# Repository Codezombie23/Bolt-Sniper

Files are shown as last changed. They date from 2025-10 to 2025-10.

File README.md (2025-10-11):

# 'Ignis' Bolt Action Sniper Blaster

## Description

Ignis is a Bolt Action Sniper rifle inspired by the Warhammer 40k Guards Sniper rifle. It uses a double stacked mag, designed by Misplaced Moose, to hold 20 rounds in a mag no longer than a normal 10 round Talon style mag.

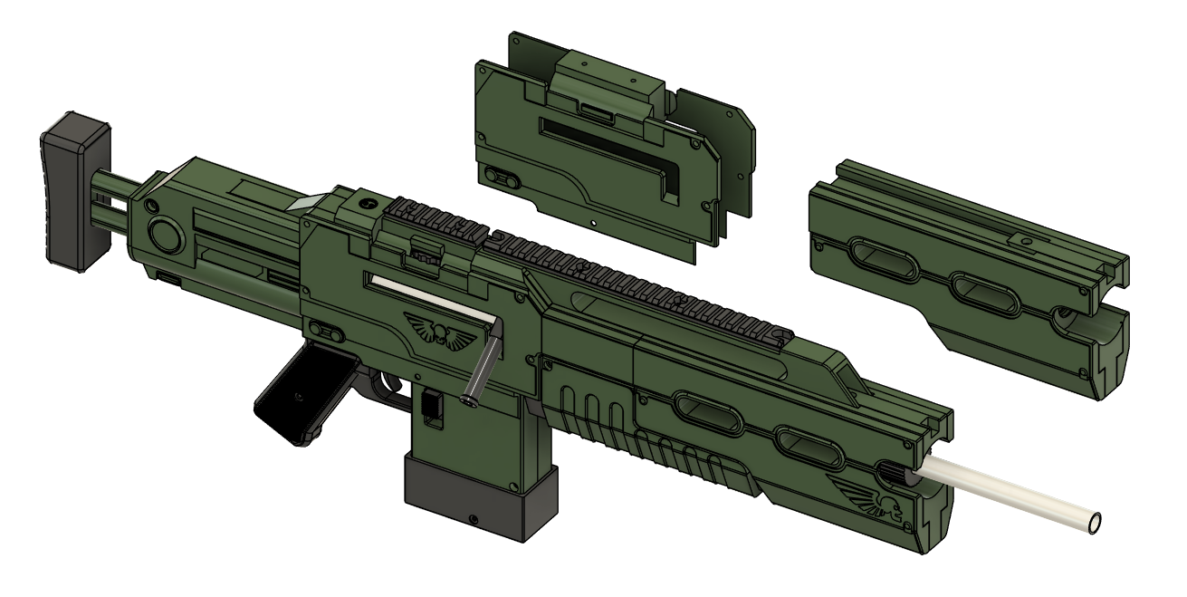
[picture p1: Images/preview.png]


### Features
- 110 > 130 adjustable FPS (WIP)
- 20 round capacity
- 450mm long barrel
- Uses Misplaced Moose's Moose Deuce double stacked mags.
- Optional adjustable optics rail

# Assembly Instructions
Start Here\
**[Assembly guide (incomplete)](Instructions/Instructions.md)**

## BOM (WIP)
- 1x - D12580 Spring - Springmasters \
	https://www.springmasters.com/shop/d12580/ 
- 4x - D11310 Spring - Springmasters \
	https://www.springmasters.com/shop/d11310/  
- 1x - 450mm Worker barrel - UK Nerfwar \
	https://www.uknerfwar.com/product-page/450mm-barrel
- 1x - 130mm Aluminium tube 38.1mm OD, 34.9mm ID - Use a supplier with a custom cutting service e.g: \
    https://www.metals4u.co.uk/materials/aluminium/aluminium-tube/986-p \
    https://www.aluminium-online.co.uk/product/1-1-4-x-16swg-aluminium-round-tube/
	
- 3x - O-Ring - 2.62mm Section 29.82mm Bore NITRILE 70 Shore Rubber O-Rings - Simply bearings
- 2x - O-Ring - 1.5mm Section 10mm Bore NITRILE 70 Shore Rubber O-Rings
- M4 Screws (todo)
- M3 Screws (todo)
- 2x - M4 grub screw (M4 x 8mm)

## Print settings
Most parts are printed at 10% gyroid or cross hatch, with three walls\
Otherwise parts are printed at four walls and 20% infill.

See instructions for more information.

# Licence
Creative Commons, Attribution-NonCommercial-ShareAlike 4.0 International \
CC BY-NC-SA 4.0 \
https://creativecommons.org/licenses/by-nc-sa/4.0/deed.en

# Attribution
- Moose Deuce Double Stack Magazines - Misplaced Moose \
	https://www.printables.com/model/1402880-double-stack-half-dart-nerf-magazines-aka-moose-du
- Cynthia - Barrel Nut and Piston front - Sillybuts \
	https://github.com/Sillybutts/Cynthia?tab=readme-ov-file

# These files are provided free of charge
However if you like these files then please consider supporting me. \
Supporting me helps pay for materials I use while prototyping. Thank you. \
You can donate via my BuyMeACoffee (Link Not available as not fully released)

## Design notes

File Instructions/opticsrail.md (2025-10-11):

# Assembling the Optics Rail
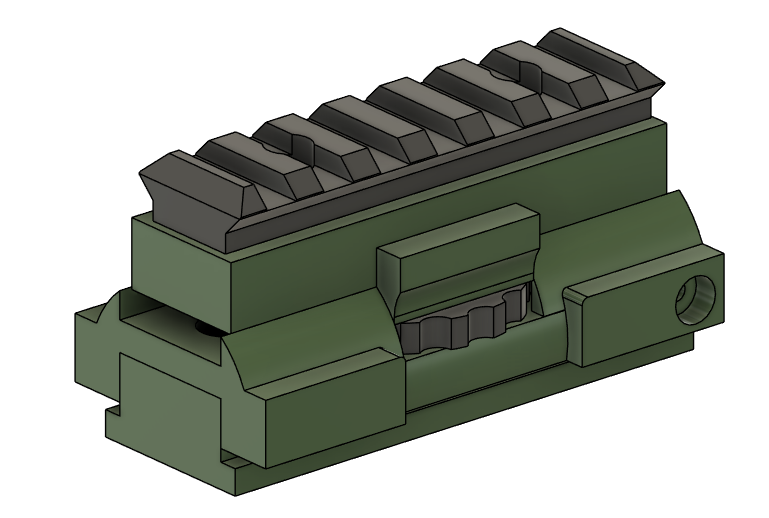
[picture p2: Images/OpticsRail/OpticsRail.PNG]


This is an optional step. When using optics there is not enough vertical control on some Optics to compensate for the short range and drop of darts. This rail allows for more vertical adjustment. If you don't plan on using Optics then you can print the solid part.

## Recommended Print Orientations

## Option 1 - Solid Optics Rail
### 3 Walls , 10% infill, No Supports needed
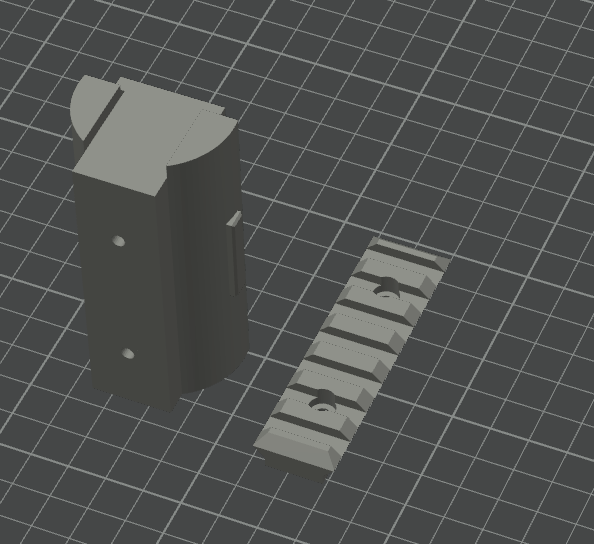
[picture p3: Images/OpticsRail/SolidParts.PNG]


## Option 2 - Adjustable Optics Rail
### 3 Walls , 10% infill, Tree Supports needed
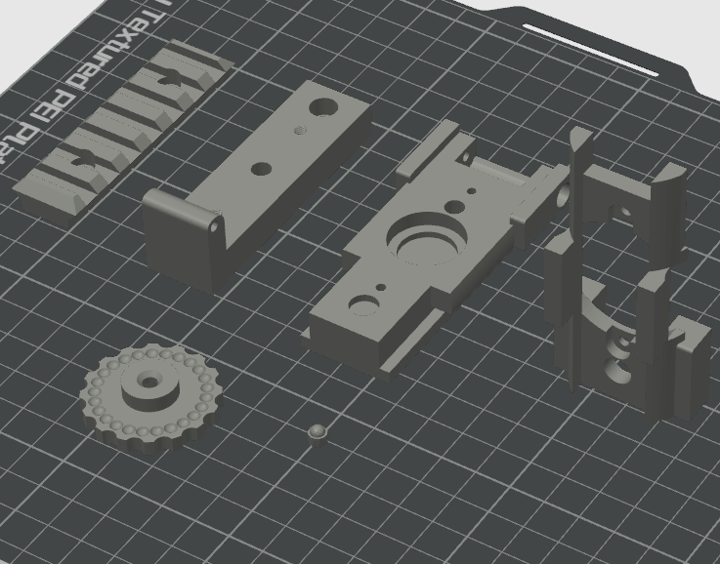
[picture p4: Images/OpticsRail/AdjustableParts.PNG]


## Tools
- 3.0mm Hex driver / Key
- 2.5mm Hex driver / Key

## Hardware

Common
- 2x M4x10 Socket Head Bolt

Option 2
- 1x 6702ZZ Bearing
- 1x 5mm x 12mm spring
- 1x 7mm x 20mm spring
- 4x M3 x 12mm Socket Head Bolt
- 1x M4 x 16mm Countersunk Screw
- 1x M4 Locknut
- 1x M4 Heatset Insert
- 2x M4 x 12mm Socket Head Bolt

## Assembly

If you are building the solid version of the optics mount, then skip to the last step.

Set a M4 heatset insert into the Optics Mount Top 
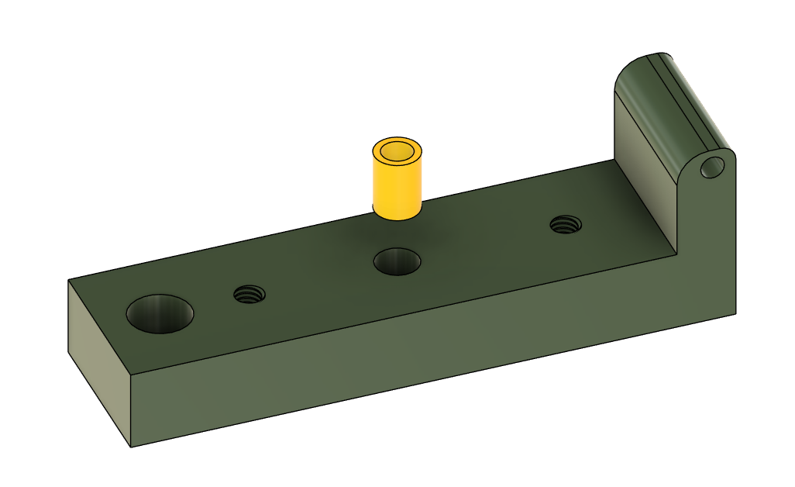
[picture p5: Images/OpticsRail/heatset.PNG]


Build the Thumb Wheel
Push the M4 Locknut into the hexagonal hole in the thumbwheel.
From the other side screw the M4 countersunk screw through the thumbwheel.
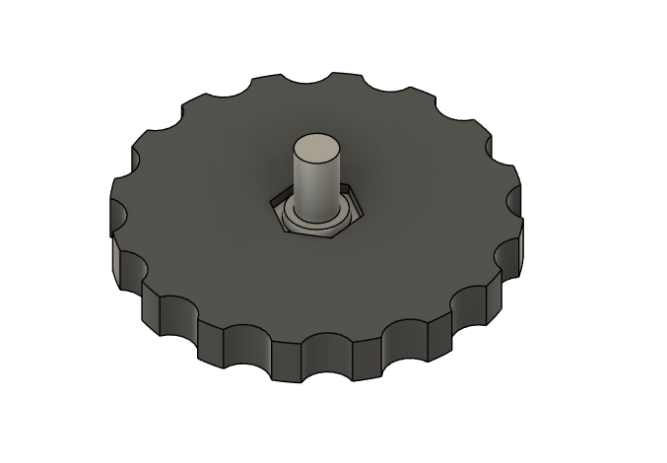
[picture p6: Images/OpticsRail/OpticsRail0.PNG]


Take the Optics Mount Lower, and press the 6702ZZ bearing into place.\
Insert the 5x12mm spring into the smaller hole, and place the locator carefully on top of the spring.
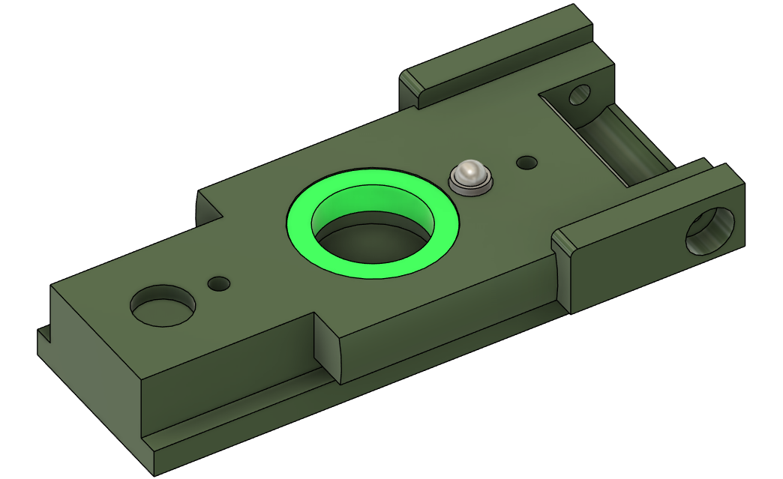
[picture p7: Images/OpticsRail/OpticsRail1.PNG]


Carefully lower the thumbwheel into the bearing in the Optics Mount Lower, taking care to not dislodge the locator.
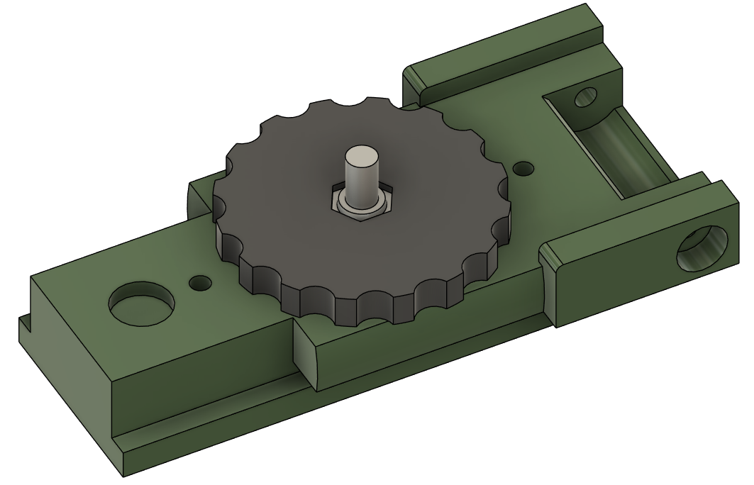
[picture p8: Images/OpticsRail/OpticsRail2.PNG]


Fit the Optics Mount Upper over the assembled parts. Again take care to ensure the wheel stays in place and the locator is not dislodged.
Use to M3x12 bolts to secure the Optics Mount Upper.
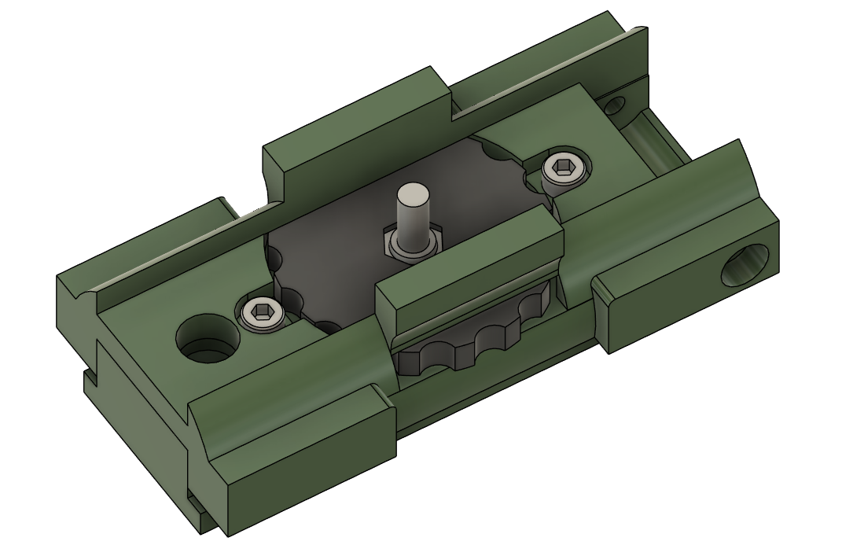
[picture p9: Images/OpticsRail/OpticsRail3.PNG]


Place the 7 x 20 Spring in the larger hole, then take the Optics Mount Top and use the thumb wheel to screw into the heatset insert in the Mount Top. 
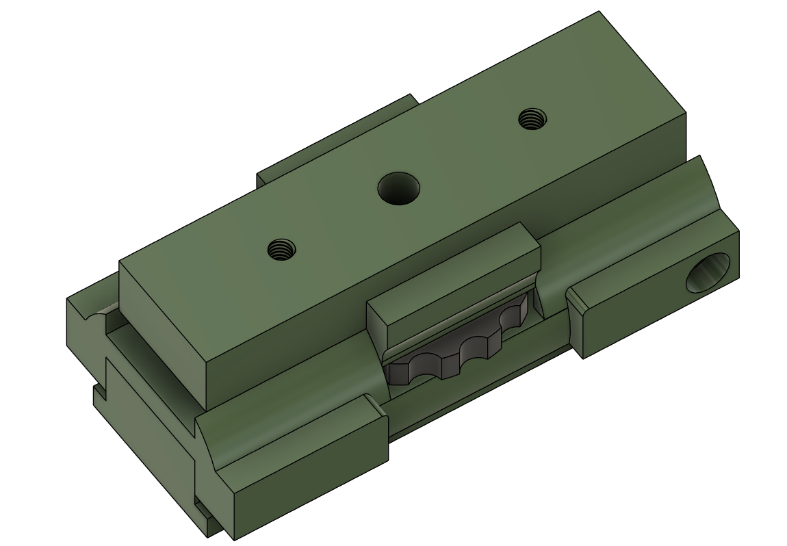
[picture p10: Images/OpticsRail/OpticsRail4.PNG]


Turn the thumb Wheel untill the side holes at the rear line up.
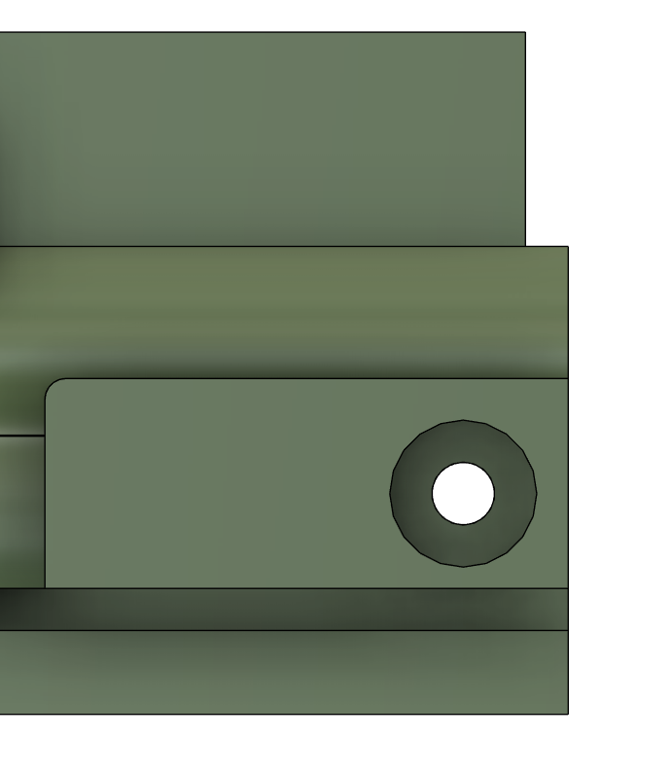
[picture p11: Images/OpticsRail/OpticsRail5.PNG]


Once the holes are lined up, screw in an M3x12mm bolt either side, once the screw is tight, back off half a turn to ensure movement.

Screw the Optics Rail into the Optics Mount Top with two M4x12 bolts. 
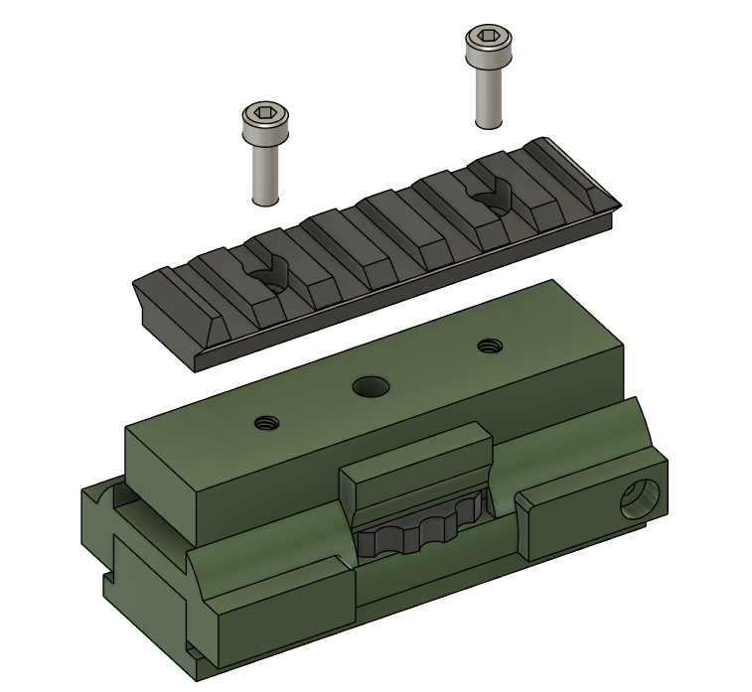
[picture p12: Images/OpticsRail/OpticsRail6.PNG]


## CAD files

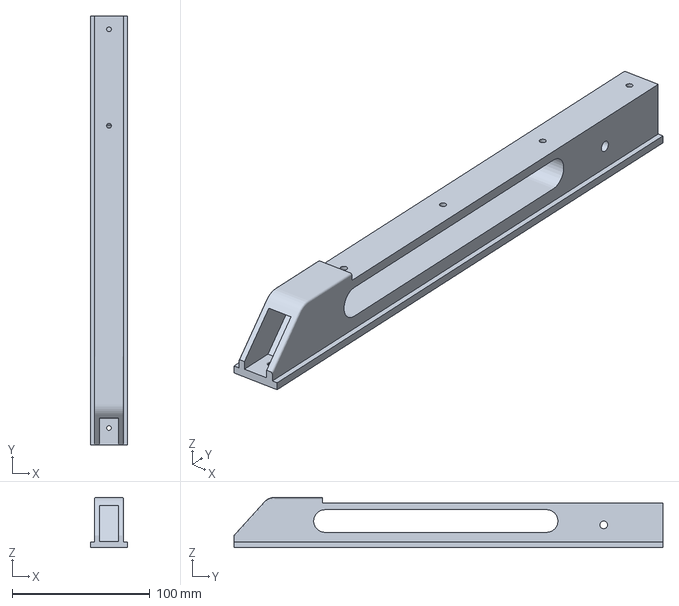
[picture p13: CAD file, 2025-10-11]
Print Files/Barrel Shroud/Upper Rail.3mf
27.2 x 311.6 x 36.5 mm

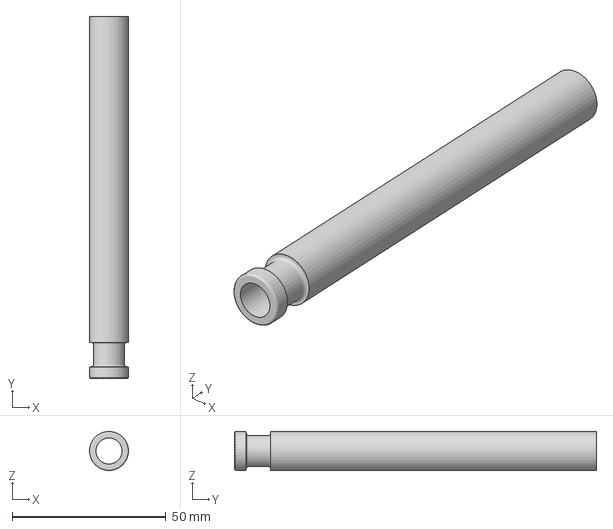
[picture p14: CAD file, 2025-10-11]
Print Files/Internals/Talon Style Ramrod Blunt.3mf
12.7 x 117.7 x 12.7 mm

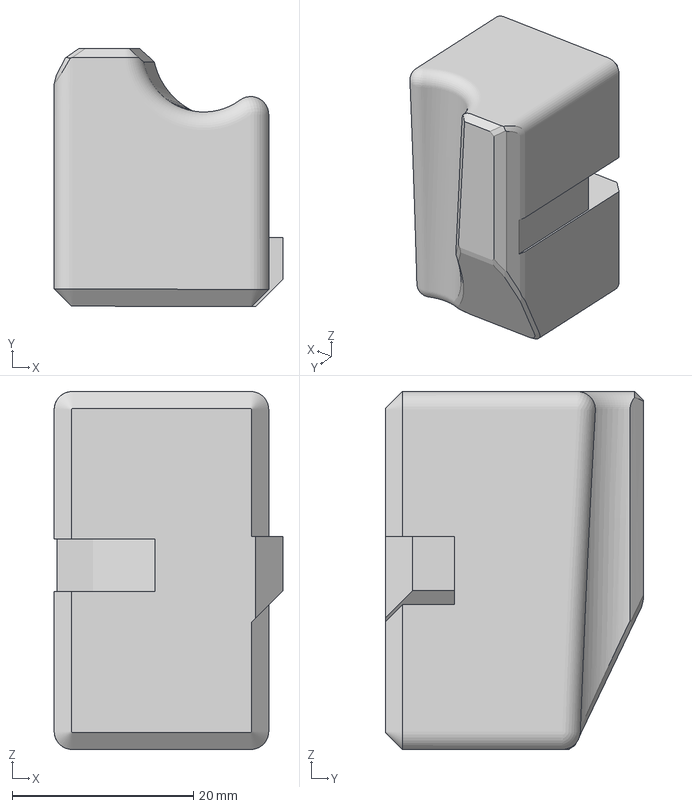
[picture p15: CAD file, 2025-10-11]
Print Files/Magazine/Follower.3mf
25.2 x 28.5 x 39.5 mm

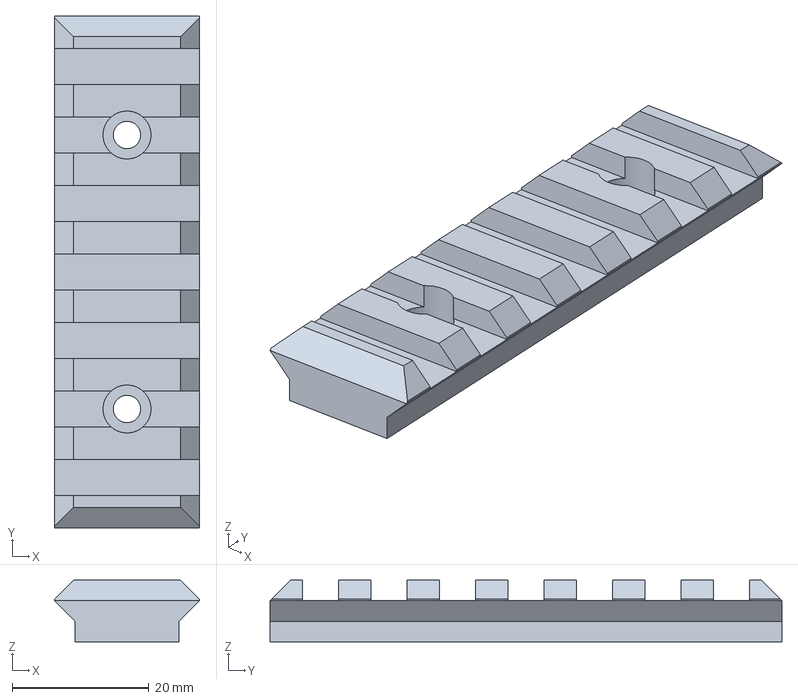
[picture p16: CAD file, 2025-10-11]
Print Files/OpticsRail/Optics Rail.3mf
21.2 x 74.8 x 9.00 mm

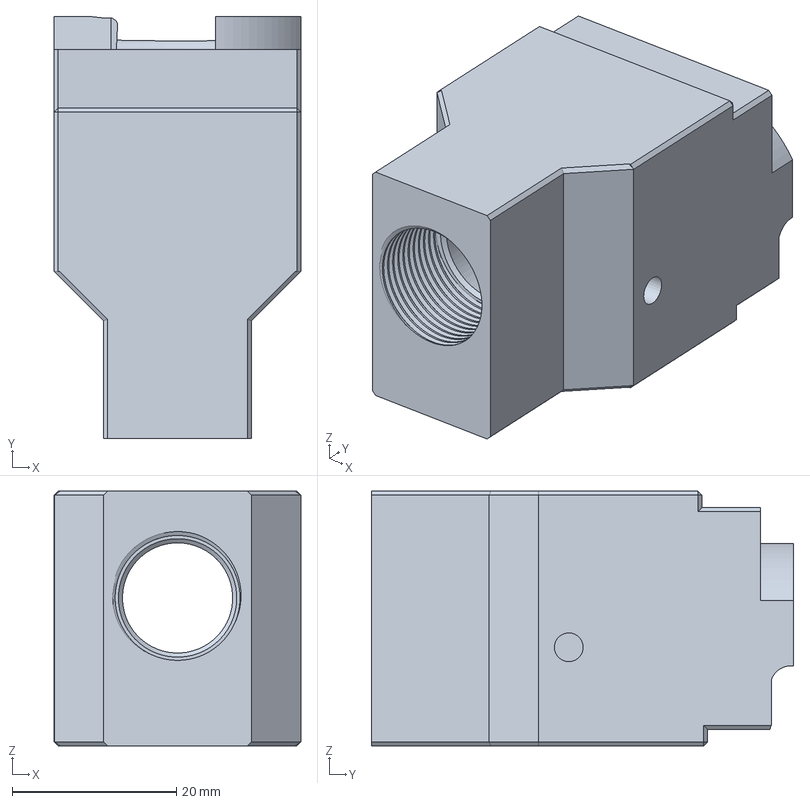
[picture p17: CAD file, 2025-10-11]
Print Files/Receiver/Feed Ramp Insert Worker Threaded.3mf
30.0 x 51.3 x 31.0 mm

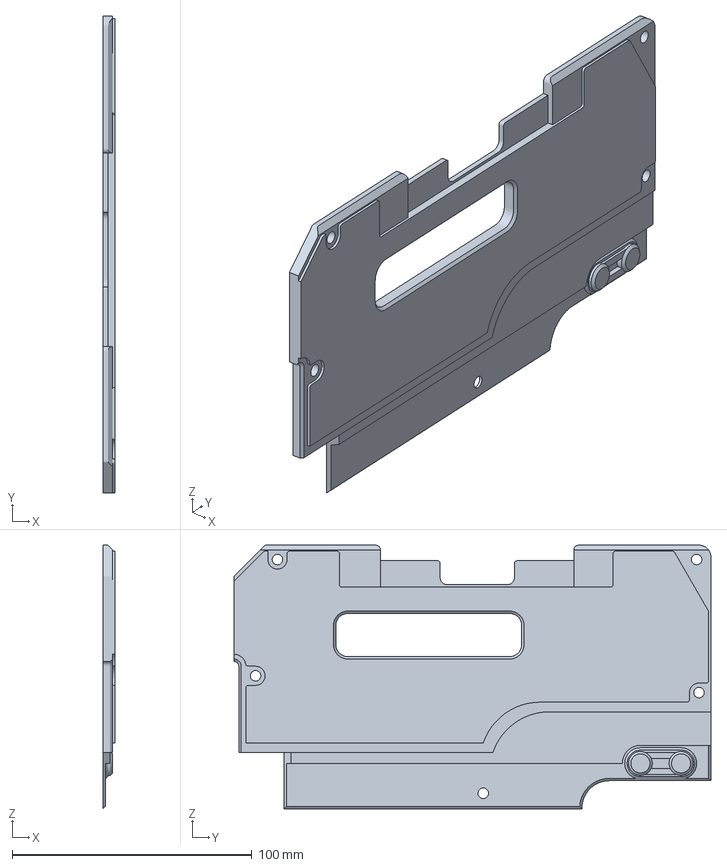
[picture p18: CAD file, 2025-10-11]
Print Files/Shell/SidePanel RHS Clean.3mf
5.00 x 199.0 x 110.0 mm

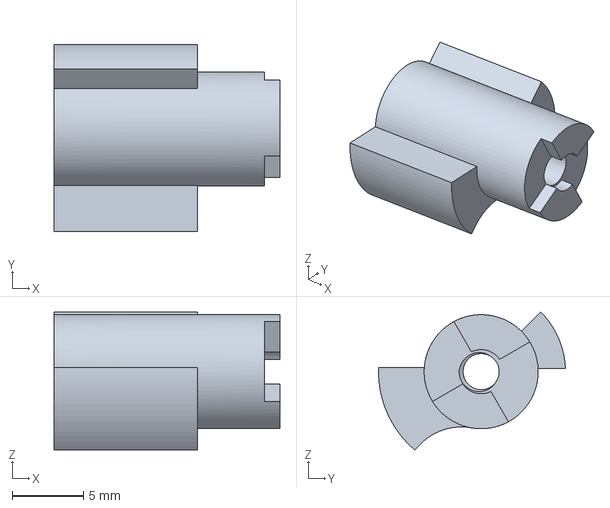
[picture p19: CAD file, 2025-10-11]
Print Files/Trigger Group/Safety Cam.3mf
15.9 x 13.1 x 9.67 mm

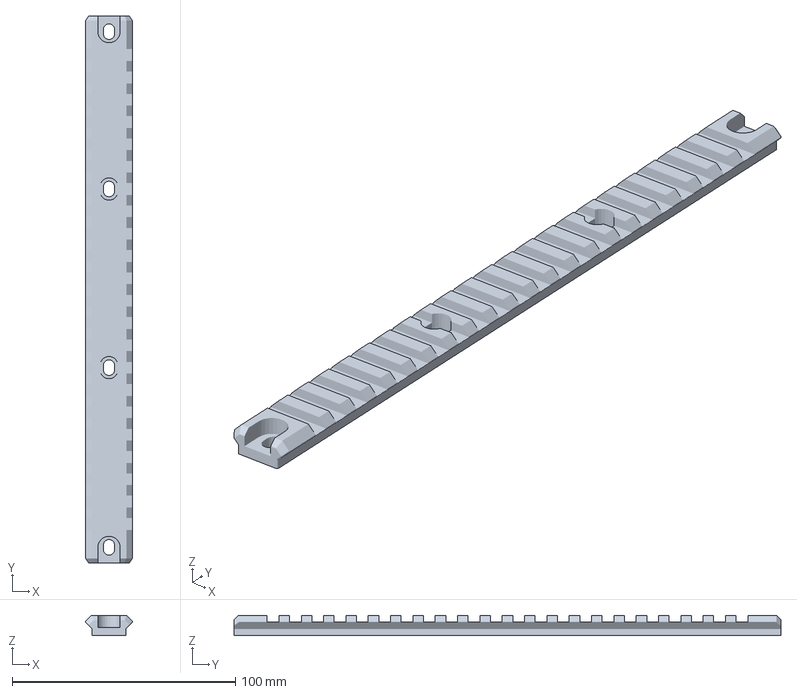
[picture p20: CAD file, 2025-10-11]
Print Files/Barrel Shroud/Rail.3mf
21.2 x 245.0 x 9.00 mm

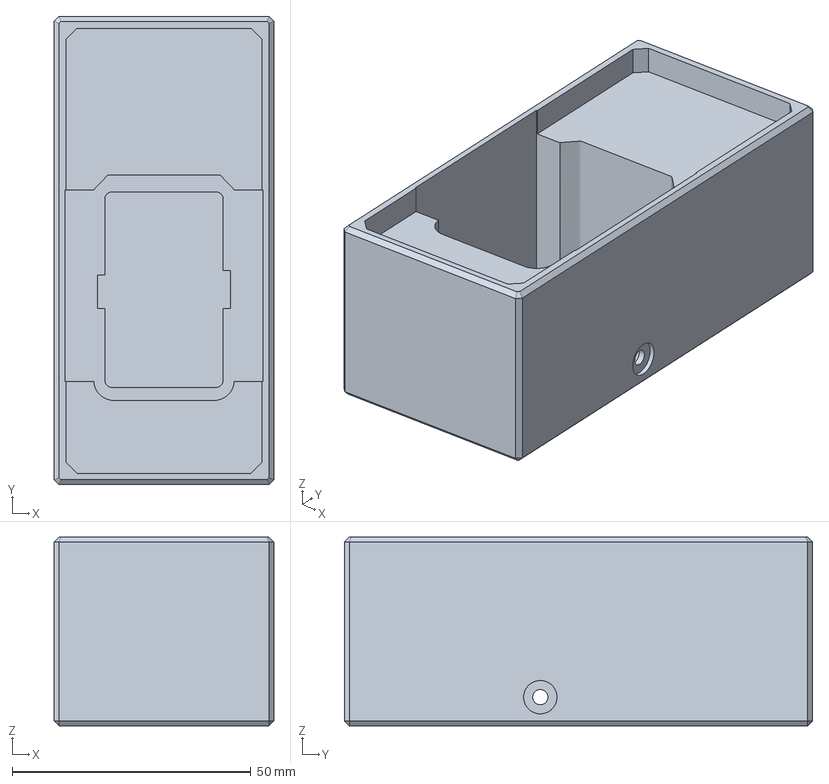
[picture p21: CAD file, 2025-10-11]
Print Files/Magazine/Double Mag Base.3mf
46.0 x 98.0 x 39.5 mm

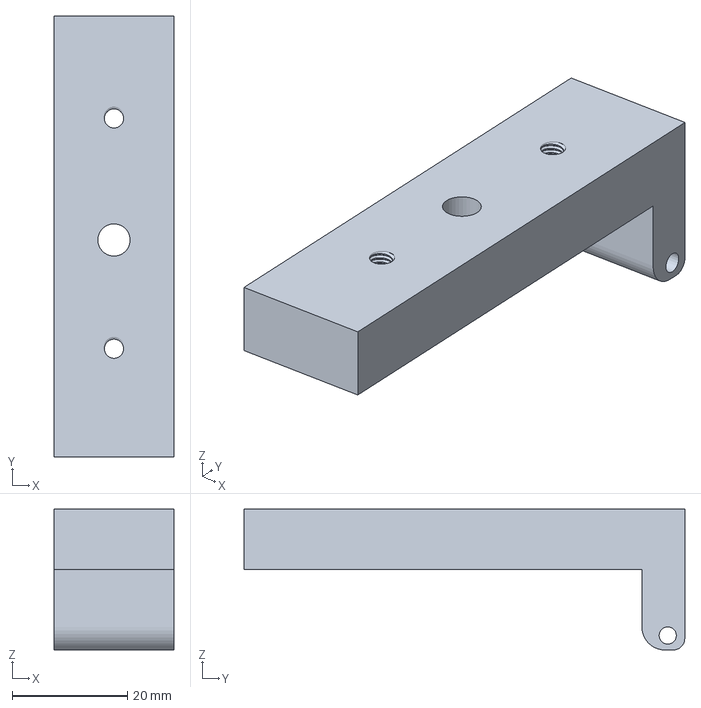
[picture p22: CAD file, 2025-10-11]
Print Files/OpticsRail/Optics Mount Top.3mf
20.8 x 76.6 x 24.5 mm

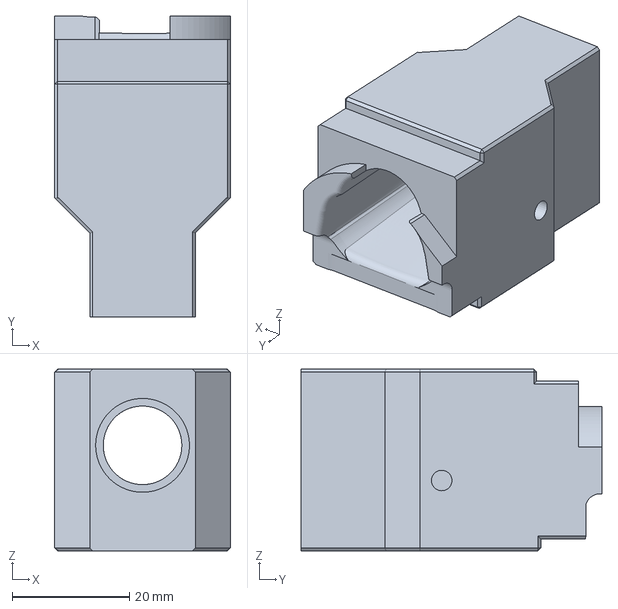
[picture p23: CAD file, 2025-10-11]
Print Files/Receiver/Feed Ramp Insert.3mf
30.0 x 51.3 x 31.0 mm

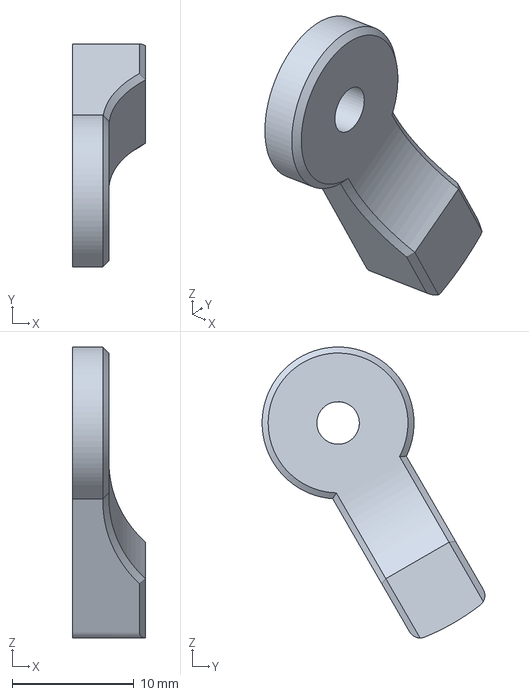
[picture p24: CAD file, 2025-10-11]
Print Files/Trigger Group/Safety Switch.3mf
6.00 x 18.3 x 23.9 mm

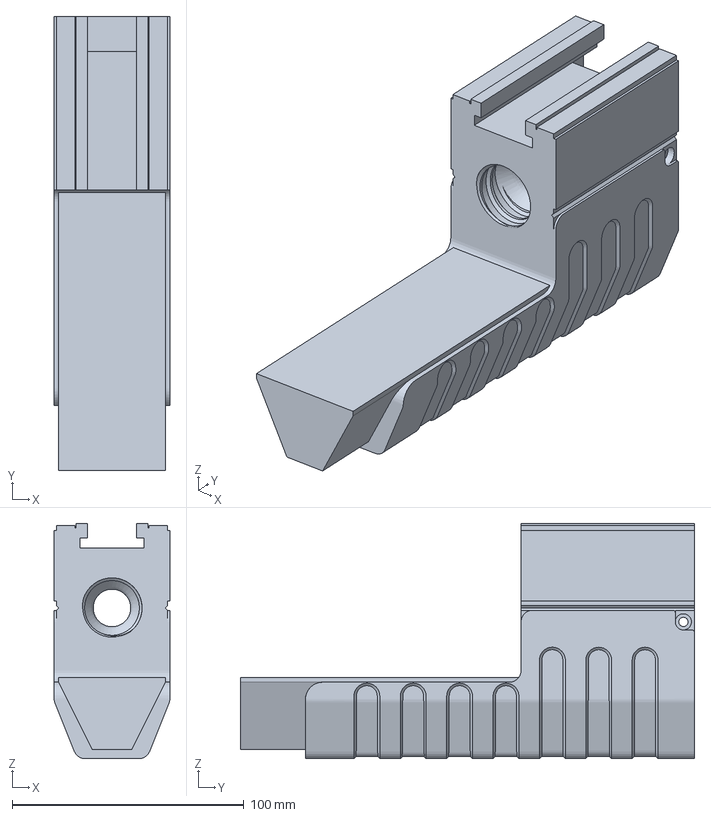
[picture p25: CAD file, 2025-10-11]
Print Files/Barrel Shroud/ForeGrip.3mf
50.0 x 195.8 x 101.5 mm

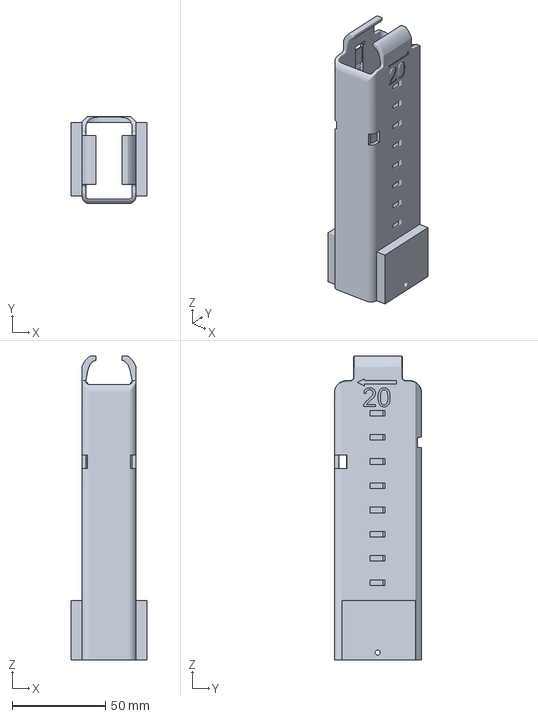
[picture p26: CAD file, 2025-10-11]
Print Files/Magazine/Double Mag.3mf
41.0 x 46.8 x 163.1 mm

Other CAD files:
Print Files/Shell/SidePanel LHS Clean.3mf
Print Files/OpticsRail/Optics Mount Lower.3mf
Print Files/Receiver/Reciever RHS Double.3mf
Print Files/Shell/Stock.3mf
Print Files/Barrel Shroud/Barrel Shroud Front.3mf
Print Files/Internals/BoltCollar.3mf
Print Files/Internals/BoltSlide OnePiece.3mf
Print Files/Internals/Charging Handle.3mf
Print Files/Internals/Piston for 37 L1.3mf
Print Files/Internals/RearShell.3mf
Print Files/OpticsRail/Locator.3mf
Print Files/OpticsRail/Optics Mount Upper.3mf
Print Files/OpticsRail/Optics Thumb Wheel.3mf
Print Files/OpticsRail/Solid OpticsMount.3mf
Print Files/Receiver/BoltSlide OnePiece.3mf
Print Files/Receiver/Feed Ramp Insert Smooth.3mf
Print Files/Receiver/Mag Release Internal.3mf
Print Files/Receiver/MagReleaseBarDouble.3mf
Print Files/Receiver/MagReleaseDouble.3mf
Print Files/Receiver/Reciever LHS Double.3mf
Print Files/Shell/Barrel Nut.3mf
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

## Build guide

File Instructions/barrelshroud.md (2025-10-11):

# Assembling the Front Barrel Shroud

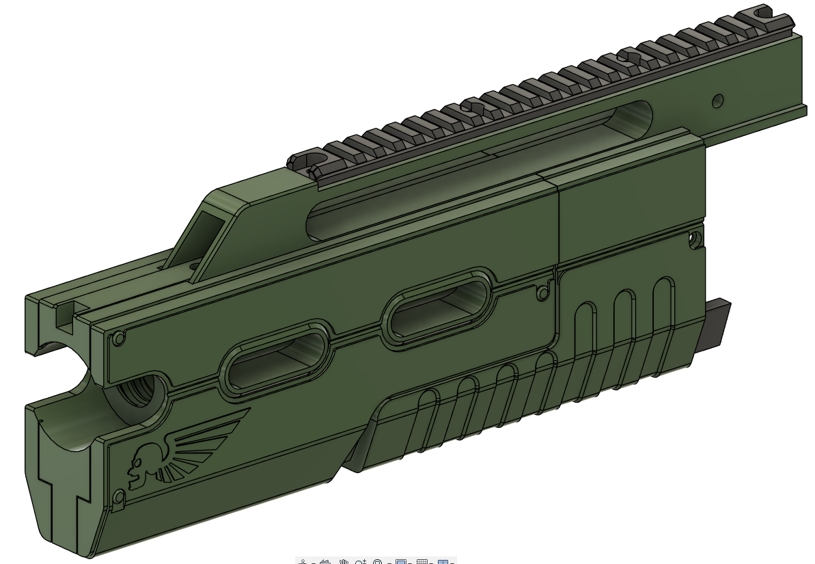
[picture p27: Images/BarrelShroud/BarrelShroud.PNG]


## Recommended Print Orientations
### 3 Walls , 10% infill

### 4 Walls , 15% infill

## Tools
- 3.0mm Hex driver / Key

## Hardware
2x M4 heatset insert
1x M4x16 socket head bolt
1x M4x12 socket head bolt
6x M4x8 socket head bolt

## Assembly

Fit two M4 Heatset inserts in the 'Upper Rail' part
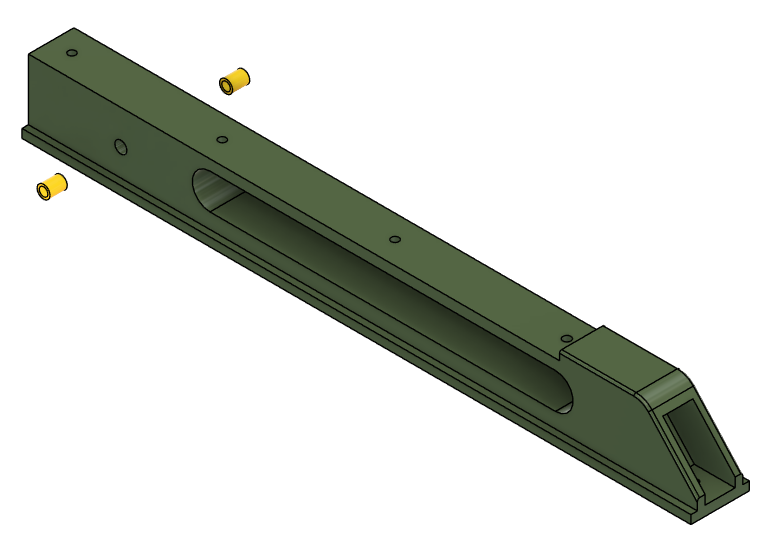
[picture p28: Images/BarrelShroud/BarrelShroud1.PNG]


Slide the 'Barrel Shroud Front' part into the upper rail and fix with an M4x16 bolt.
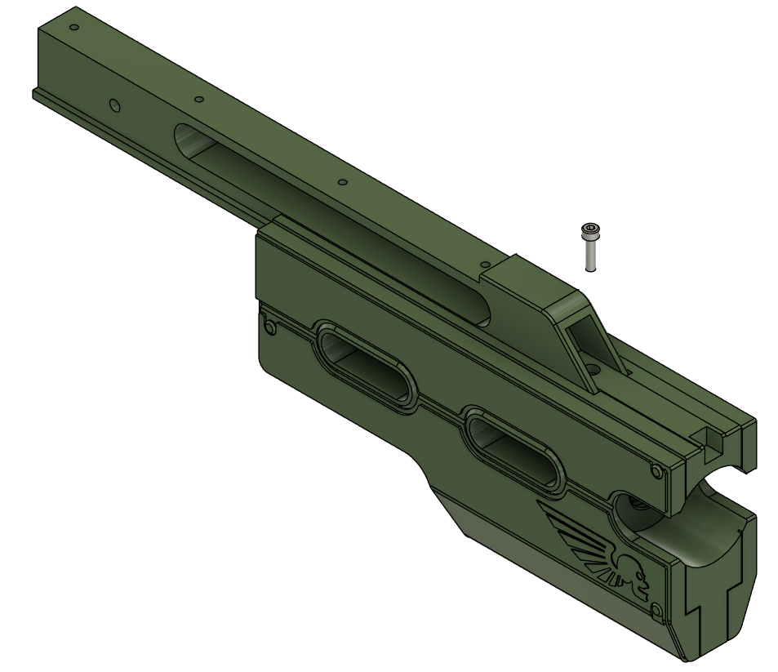
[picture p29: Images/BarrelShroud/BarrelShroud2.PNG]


Slide the Fore Grip into place and secure with an M4x12 bolt
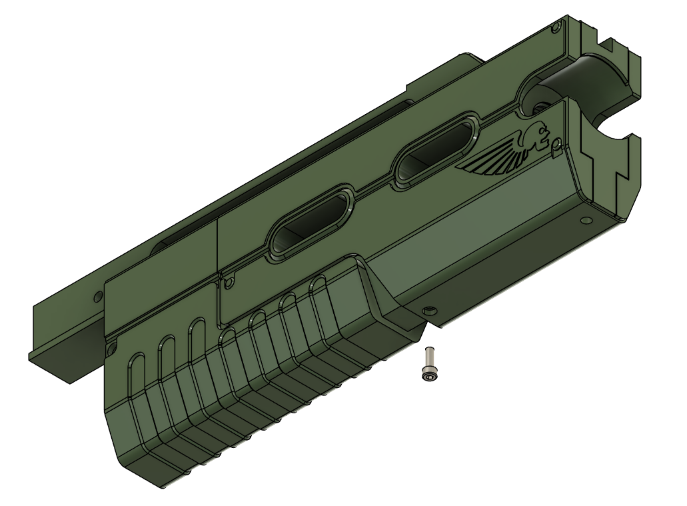
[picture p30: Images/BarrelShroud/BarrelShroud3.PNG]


Attach the Rail with four M4x8 bolts.
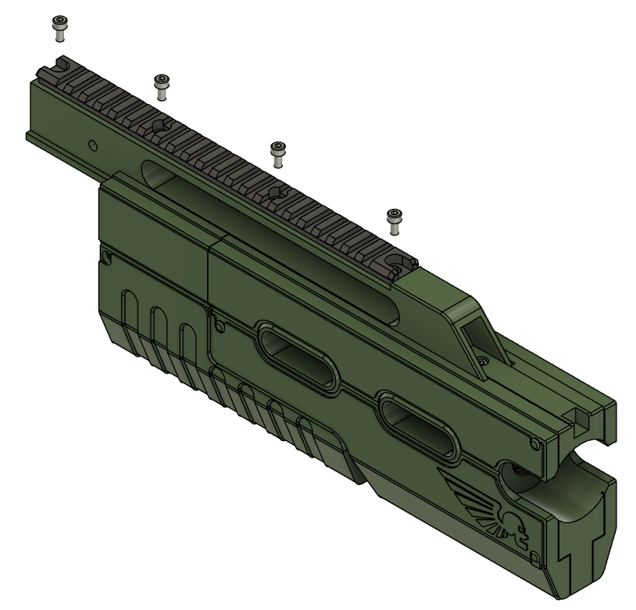
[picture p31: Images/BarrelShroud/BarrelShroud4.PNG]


Slide the completed assembly onto the front of the blaster, and secure with two m4x8 bolts.
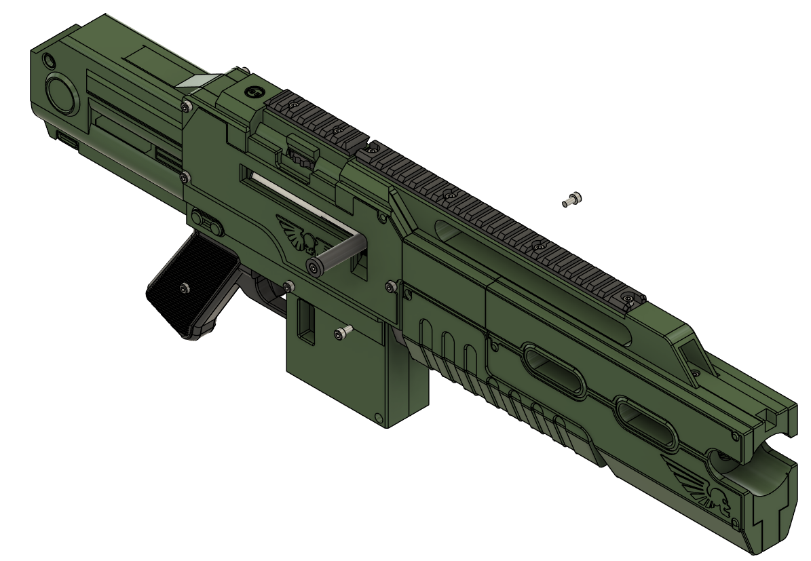
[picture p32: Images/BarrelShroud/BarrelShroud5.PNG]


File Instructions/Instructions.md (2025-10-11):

# Assembly Guide

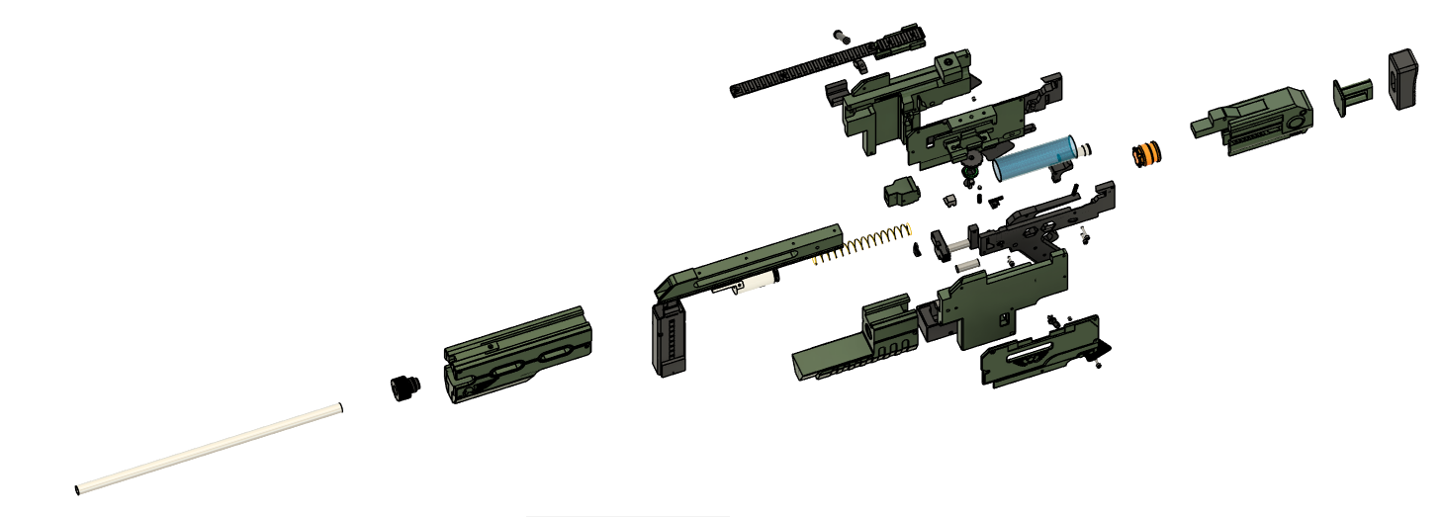
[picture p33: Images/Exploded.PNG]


## Parts

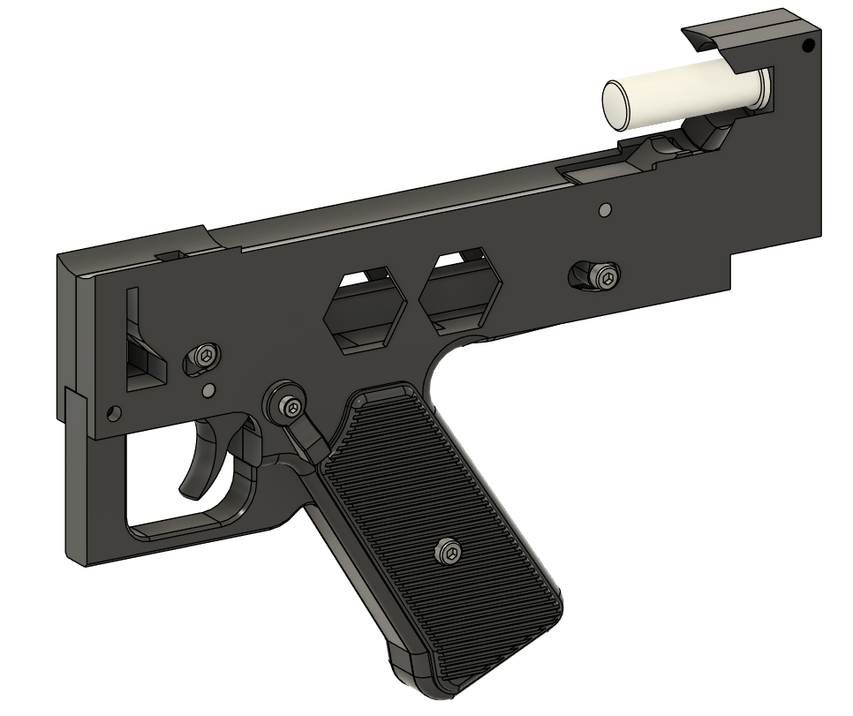
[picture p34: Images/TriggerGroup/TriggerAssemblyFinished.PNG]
 [Assembling the Trigger Group](triggergroup.md).

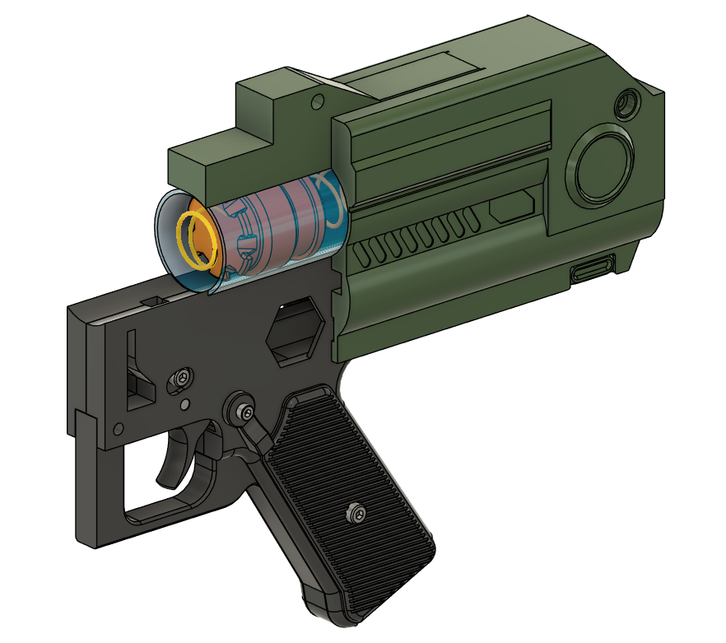
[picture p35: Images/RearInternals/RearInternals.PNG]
 [Assembling the Rear Internals](rearinternals.md).

 [Optional: Assembling the Optics Rail](opticsrail.md).

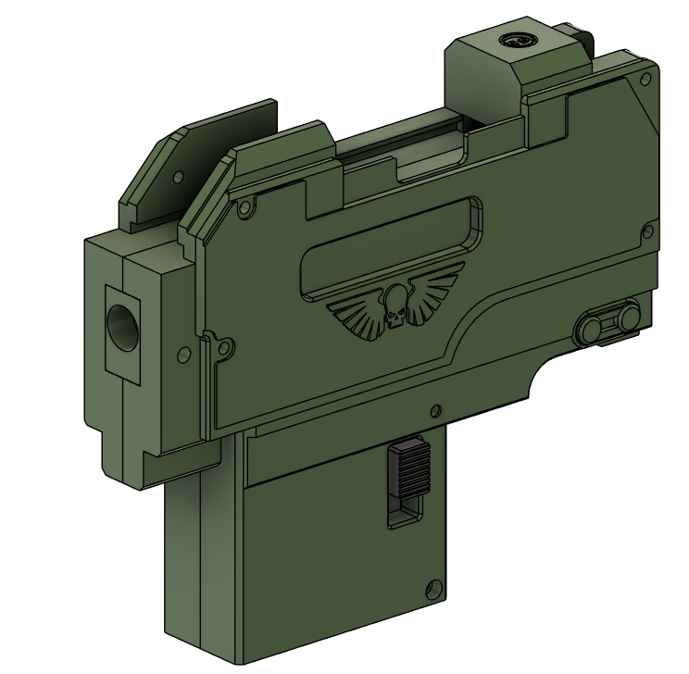
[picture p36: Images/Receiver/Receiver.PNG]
 [Assembling the Receiver](receiver.md).

 [Assembling the Front Barrel Shroud](barrelshroud.md).

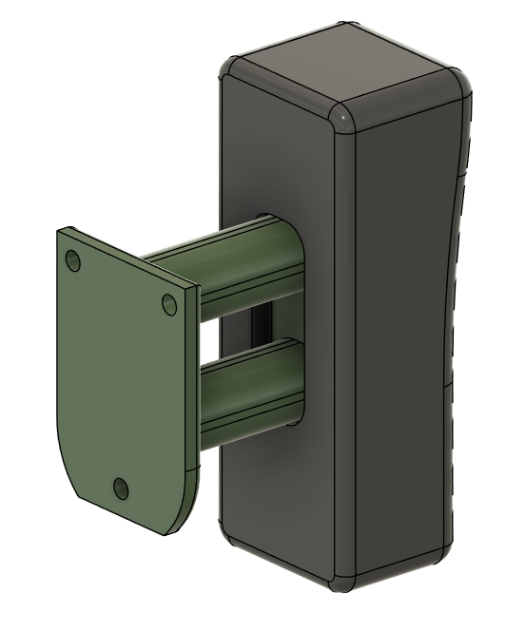
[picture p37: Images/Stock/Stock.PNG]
 [Assembling the Stock](stock.md).

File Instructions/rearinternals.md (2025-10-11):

# Assembling the Rear Internals



## Recommended Print Orientations

### 4 Walls , 15% infill, Tree Support On
BoltSlide OnePiece, Piston, BoltCollar, Charging Handle\
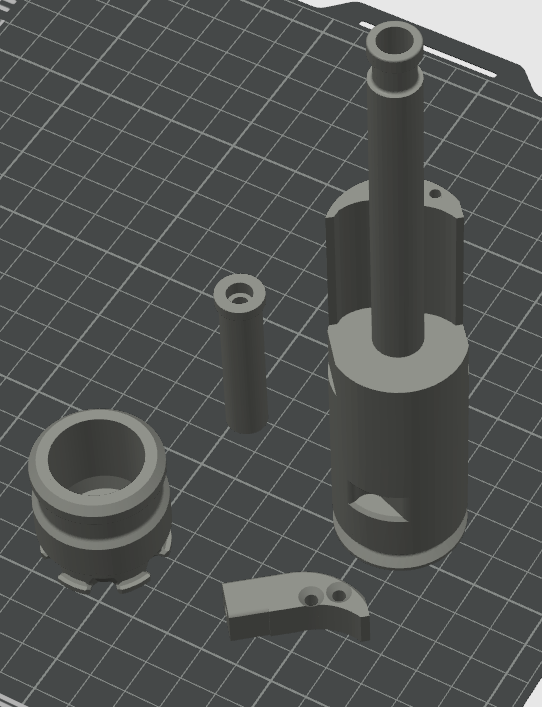
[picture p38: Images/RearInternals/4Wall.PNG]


### 3 Walls , 10% infill, No Supports needed
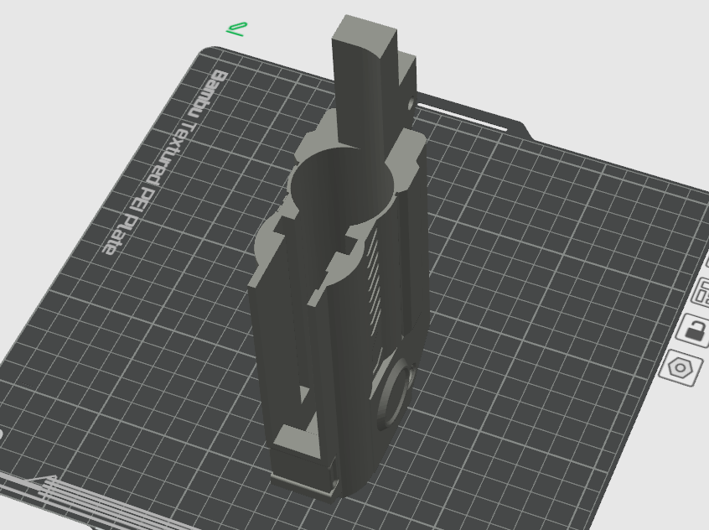
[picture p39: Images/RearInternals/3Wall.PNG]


## Tools
- 3.0mm Hex driver / Key

## Hardware

- 2x M4 Heatset Inserts
- 1x 130mm Aluminium Plunger tube
- 2x M4x12 Socket Head Bolts
- 1x Silicone Oil (1000ct)

## Assembly

Put aside the BoltSlide OnePiece, BoltCollar and Charging Handle, these will be fitted in a later step

Set the heat inserts into the RearShell as shown\
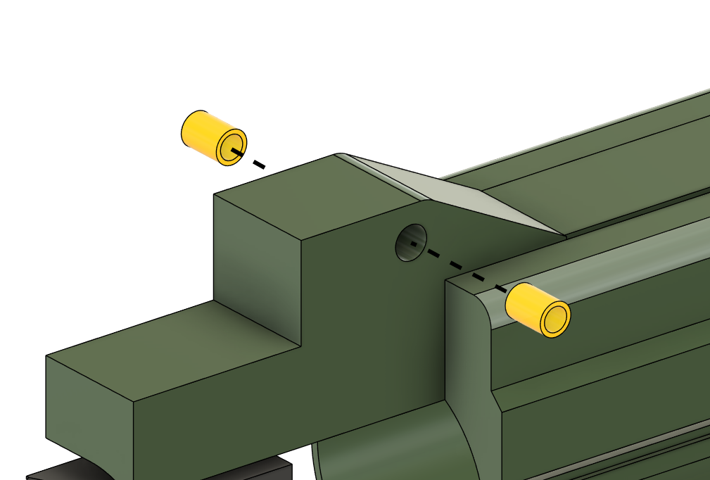
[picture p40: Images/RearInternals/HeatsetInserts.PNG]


Ensure the edges of the plunger tube are free of any burrs from cutting and file any burrs away is needed.\
Very Important. Carefully clean the inside of the plunger tube, make sure it is entirely free of any aluminium shavings or particles from cutting/filing.\
Put three or four small drops of 1000ct Silicone Oil into the inside of the plunger tube, and wipe it through to ensure that all of the interior surface of the plunger tube is thinly coated.

Place the plunger tube onto the Trigger Group
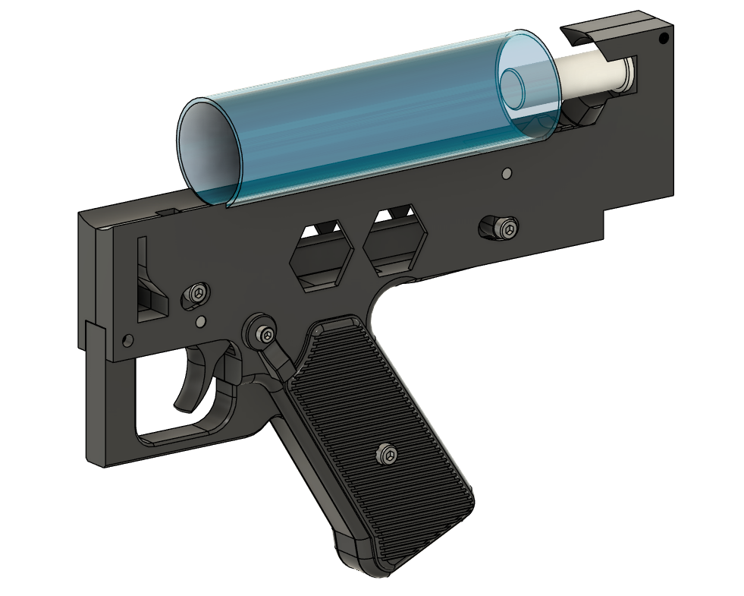
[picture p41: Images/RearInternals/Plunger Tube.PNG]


And slide the RearShell over the plunger tube 
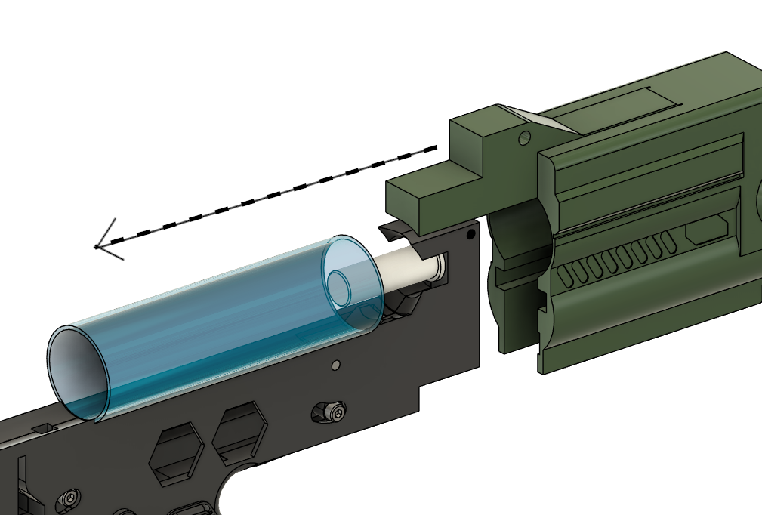
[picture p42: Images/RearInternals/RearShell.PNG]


Screw in two M4x12 bolts into the rear shell
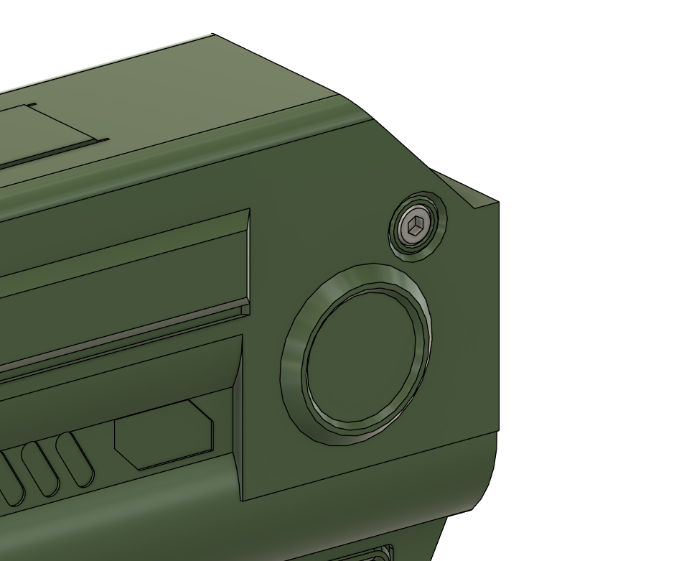
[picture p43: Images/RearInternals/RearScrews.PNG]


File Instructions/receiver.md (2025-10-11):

# Assembling the Receiver for Double Stacked Magazines



## Parts and Recommended Print Orientations

If you are planning to use a threaded Worker barrel then its recommended that you print
- Feed Ramp Insert Worker Threaded

If you are using an unthreaded aluiminium barrel then its recommended you print
- Feed Ramp Insert Smooth

This guide assumes the threaded insert is being used, but the instructions are the same regardless.

### 3 Walls , 10% infill

### 4 Walls , 15% infill

## Tools
- 2.0mm Hex Driver / Key
- 2.5mm Hex driver / Key
- 3.0mm Hex driver / Key

## Hardware
2x M4 Heatset inserts
3x 2.62mm Section 29.82mm Bore NITRILE 70 Shore Rubber O-Rings 
2x 1.5mm Section 10mm Bore NITRILE 70 Shore Rubber O-Rings
1x 1000ct Silicone Oil
1x M4x60 Socket head bolt
5x M4x20 Socket head bolt
2x M4x8 Socket head bolt
2x M4x12 Socket head bolt
2x 7x20mm spring
1x M3x12 Socket head bolt

## Assembly

Fit the M4 heatset inserts into the front end of of each of the receiver halves.
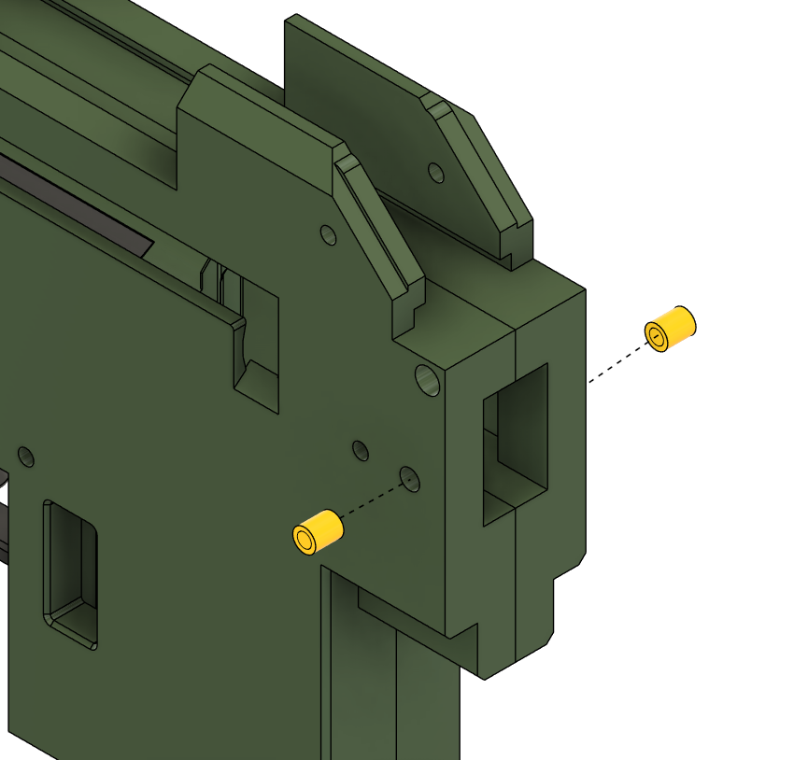
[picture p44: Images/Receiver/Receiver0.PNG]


Place two 29.8mm bore o-rings over the piston. On the outer o-ring clip it over three of the protrusions on the front of the piston as shown.
Put a small amount of silicone oil over the piston o-rings.

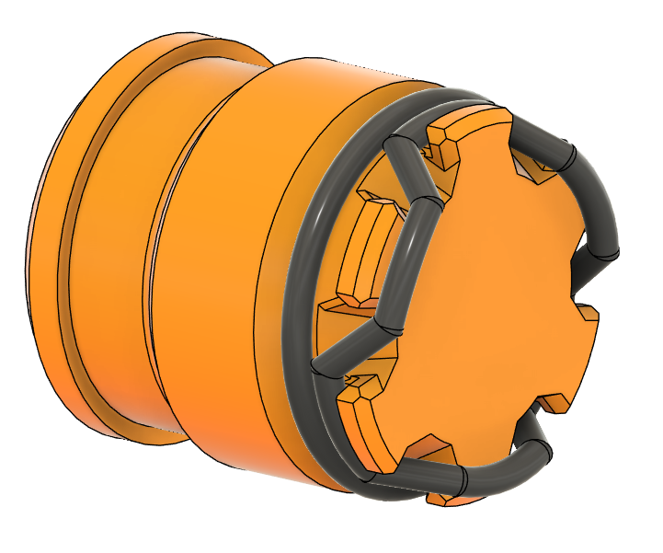
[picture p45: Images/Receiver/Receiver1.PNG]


Insert the D12580 spring (or equivalent) into the plunger tube, and place the piston over the spring.

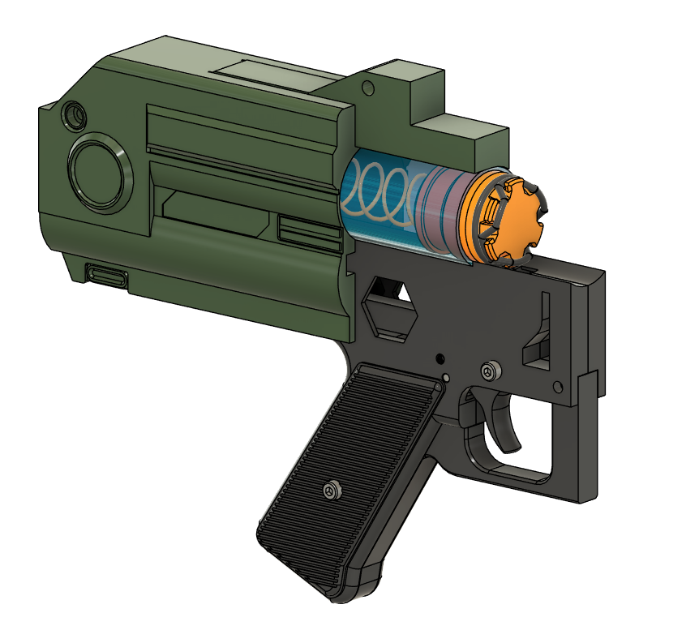
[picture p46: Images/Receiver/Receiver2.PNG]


Take part 'BoltSlide OnePiece' and place a 29.8mm bore O-ring into the rear groove, take two of the smaller 10mm bore o-rings and fit them into the front groove. 
Put a couple of drops of Silicone oil over the O-Ring at the back, and O-Rings at the front, wipe off any excess.
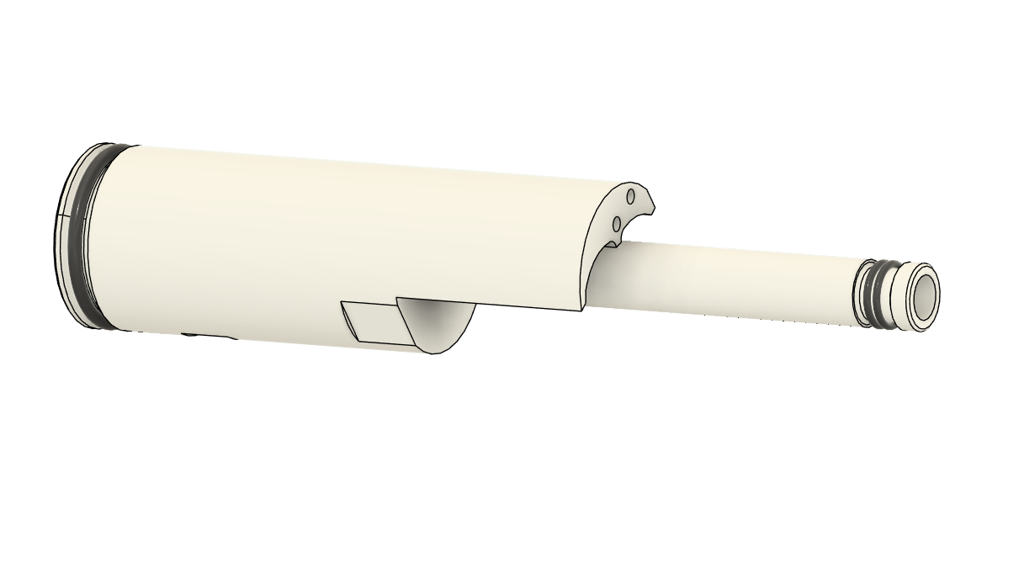
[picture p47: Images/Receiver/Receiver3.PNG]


Take the part 'BoltCollar' and two M3 x 16mm countersunk screws, and screw the BoltCollar into the 'BoltSlide OnePiece' 
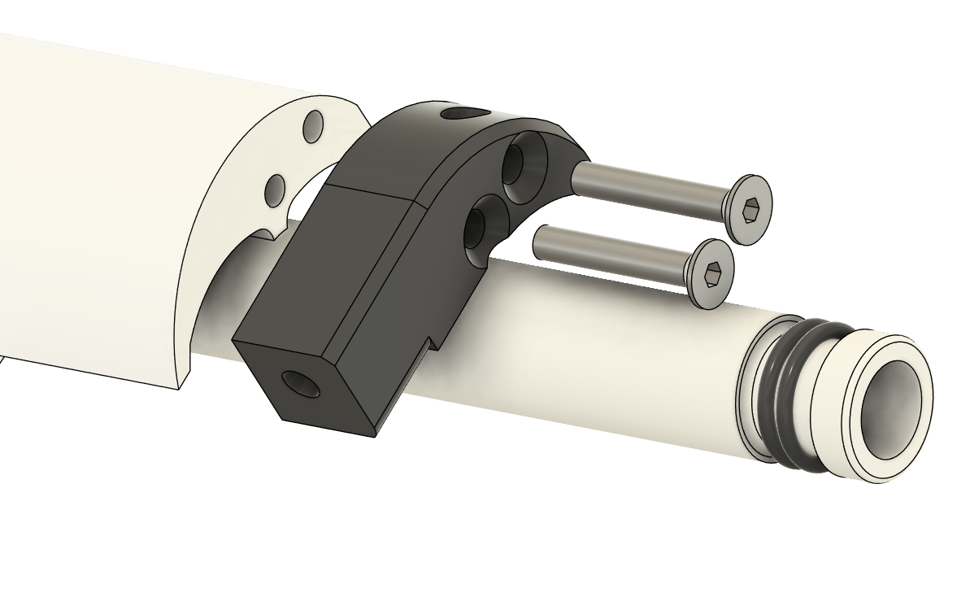
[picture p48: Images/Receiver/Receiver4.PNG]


Take the 'Charging Handle' and an M4x60 bolt, and screw both into the BoltCollar to complete the Bolt Slide.
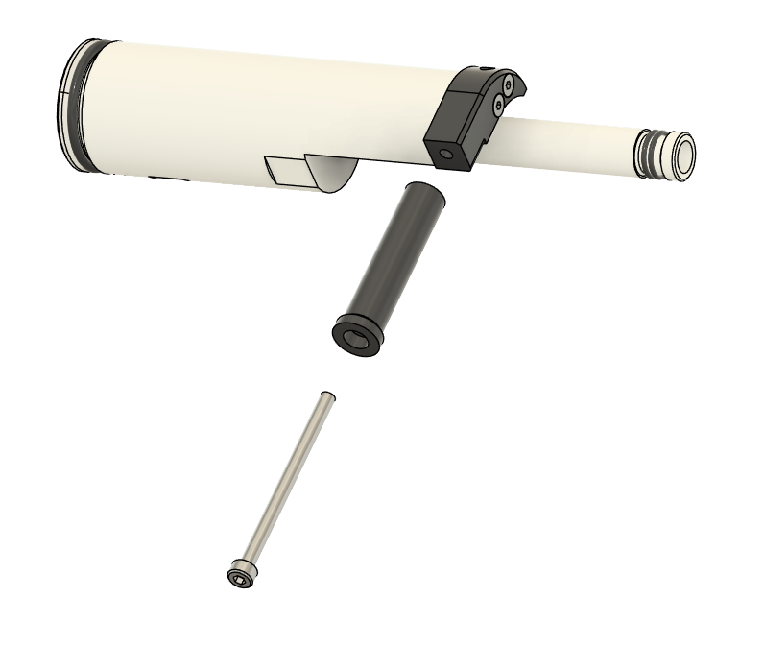
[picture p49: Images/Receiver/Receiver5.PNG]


Take the Rear Assembly, the completed bolt slide and 'Reciever RHS Double'\
Use the Bolt Slide to compress the piston down into the pluger tube and press the bolt slide into the plunger tube.\
Take care to ensure the bolt slides O-Ring fits properly and is not pinched by the edge of the plunger tube.\
At this point do not push the bolt slide to far down the plunger tube, just past the O-Ring as shown below is fine.
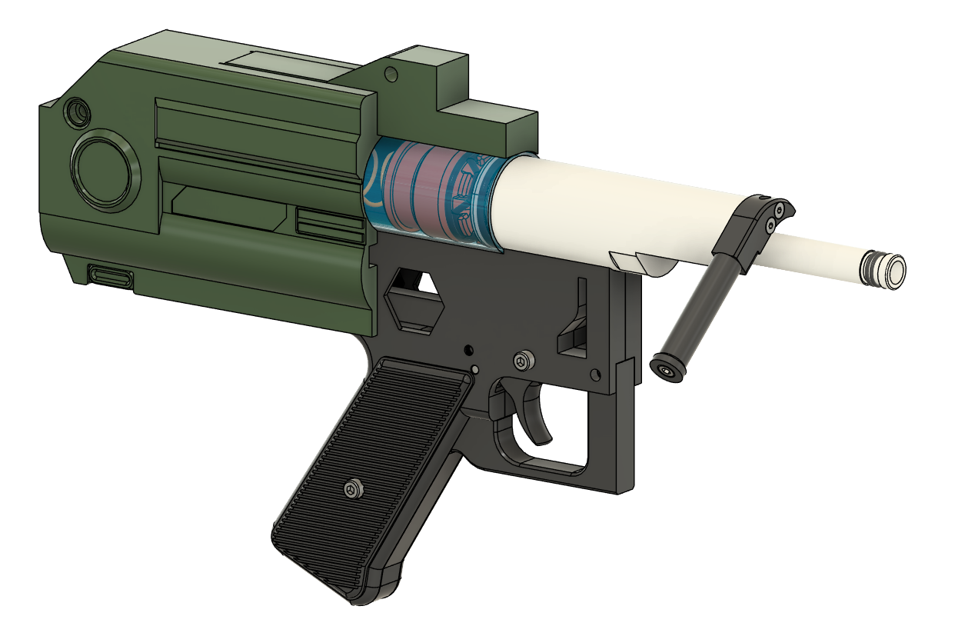
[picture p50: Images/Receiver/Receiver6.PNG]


Holding the bolt slide in place, take the 'Reciever RHS Double' and slide it into place into the odd shaped hole in the grip.
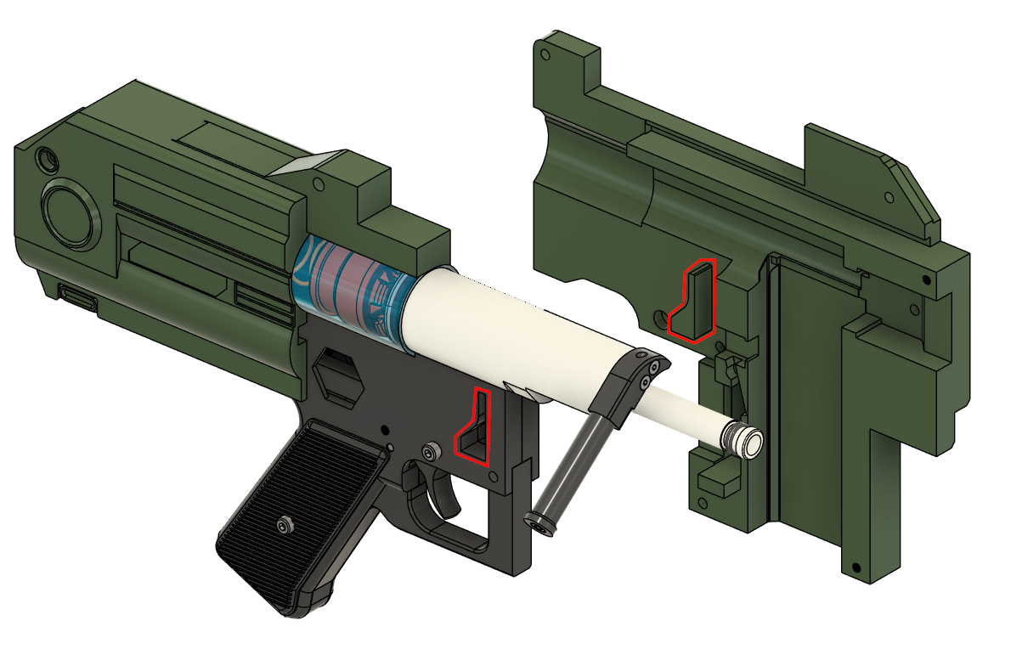
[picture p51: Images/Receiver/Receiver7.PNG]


Once 'Reciever RHS Double' is in place you can gently release the Bolt slide and settle it into the side of the reciever, the Bolt Slide will rest naturally on its stops.
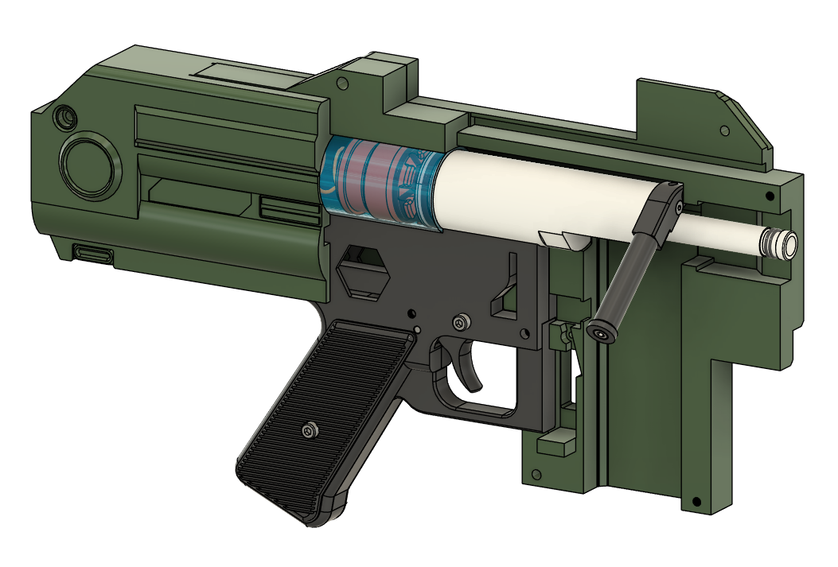
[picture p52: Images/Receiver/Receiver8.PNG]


Next we will secure the Grip section to the Right hand side of the receiver.
Take 'SidePanel RHS' and a M4x20 screw and screw both into the hole shown below, taking care to not dislodge the Bolt Slide while doing so.
Screw an additional M4x20 into the Rear Shell, and an M4x8 into the receiver as shown.
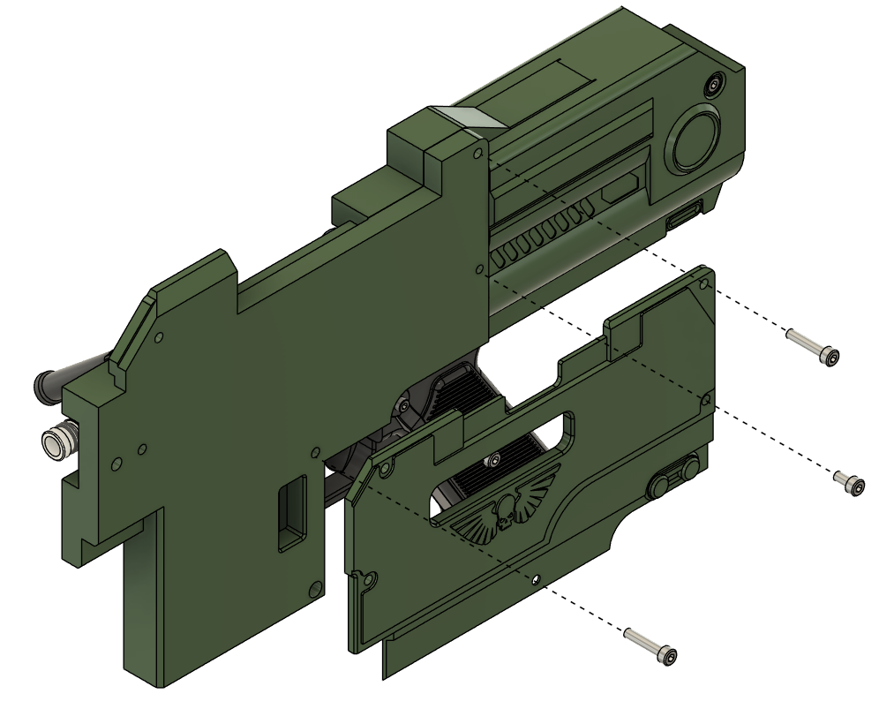
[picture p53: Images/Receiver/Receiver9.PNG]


Slide the Feed Ramp Insert (either Worker threaded or Smooth depending on which barrel you intend to use) into place and secure with an M4x12 bolt.\
(Tip: if using the threaded barrel, check that the barrel screws smoothly into the threaded version of the Freed Ramp Insert before fitting, if its stiff or squeaks, a drop of Silicone Oil can help)

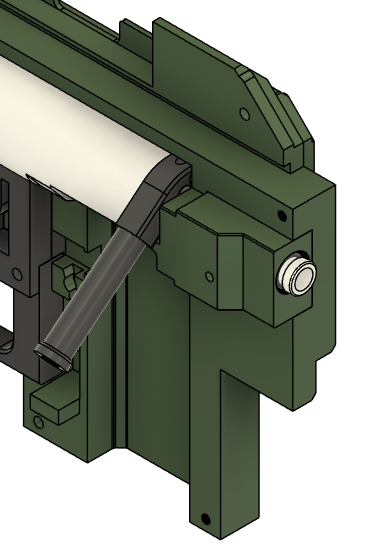
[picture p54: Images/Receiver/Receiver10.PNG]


Installing the mag release.
Take the 'Mag Release Internal' part and 'MagReleaseBarDouble' place these together into the receiver.
(Note the orientation of the MagReleaseBarDouble part in the picture.
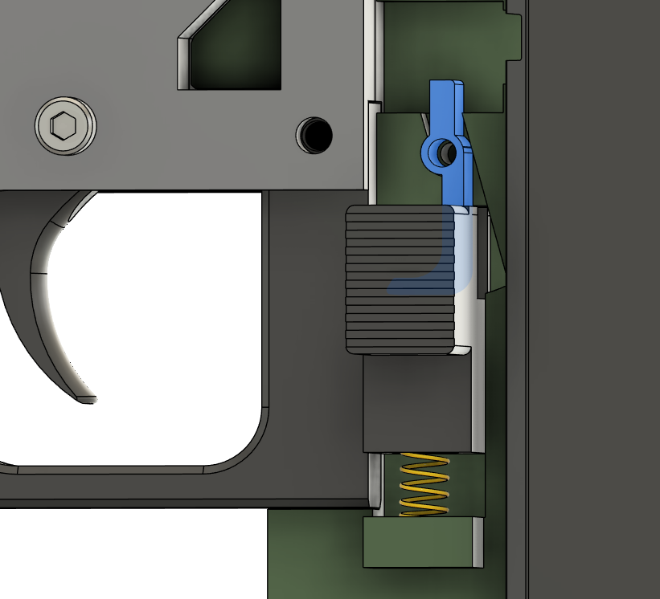
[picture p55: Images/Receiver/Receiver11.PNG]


Fit the MagReleaseDouble part along with the second 7x20mm spring.
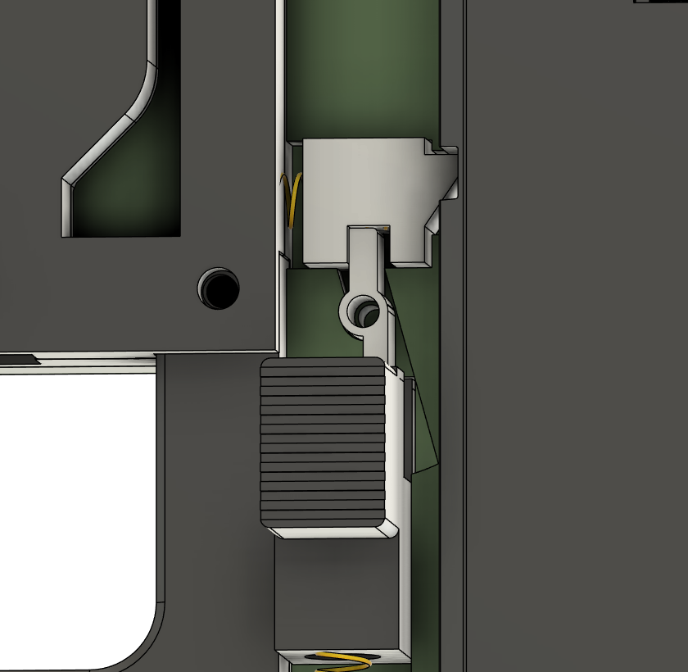
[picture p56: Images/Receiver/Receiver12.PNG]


Press the Optics Mount into place.

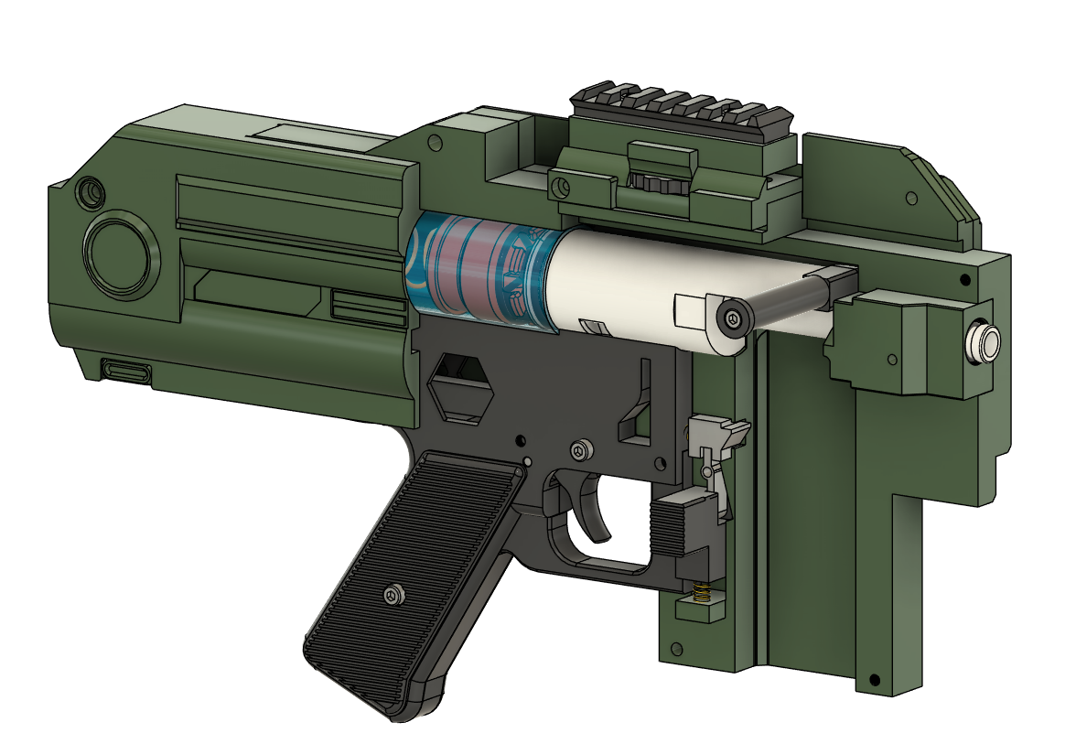
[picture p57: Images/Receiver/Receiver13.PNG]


Close the Receiver by fitting the 'Reciever LHS Double', to make it easier to fit, rotate the charging handle to the up position.
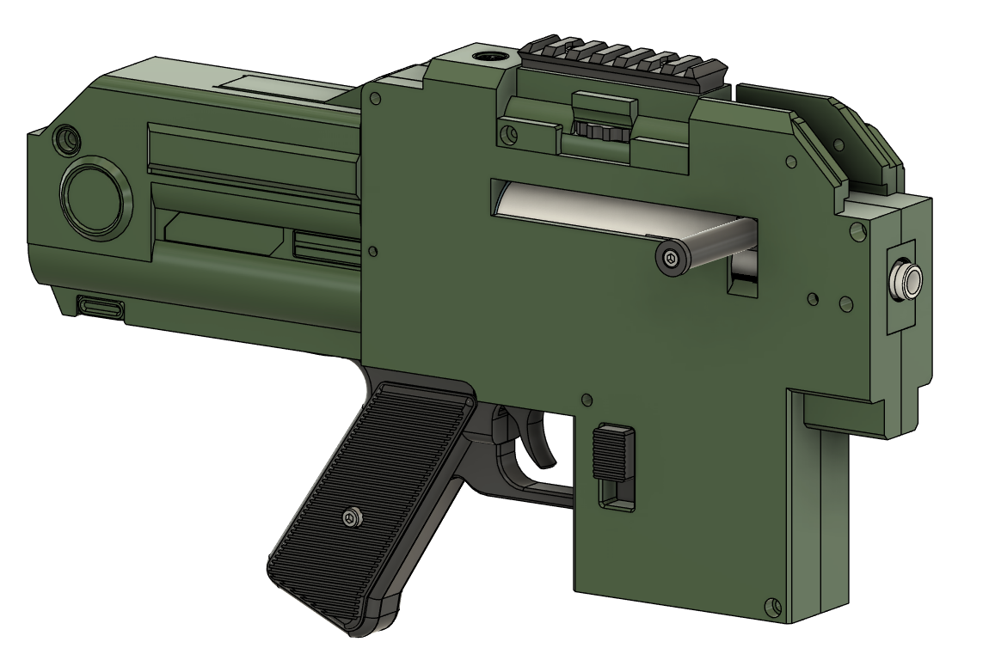
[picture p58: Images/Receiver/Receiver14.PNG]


Screw in the 'SidePanel LHS' using two M4x20, one M4x8 screw and M4x12.
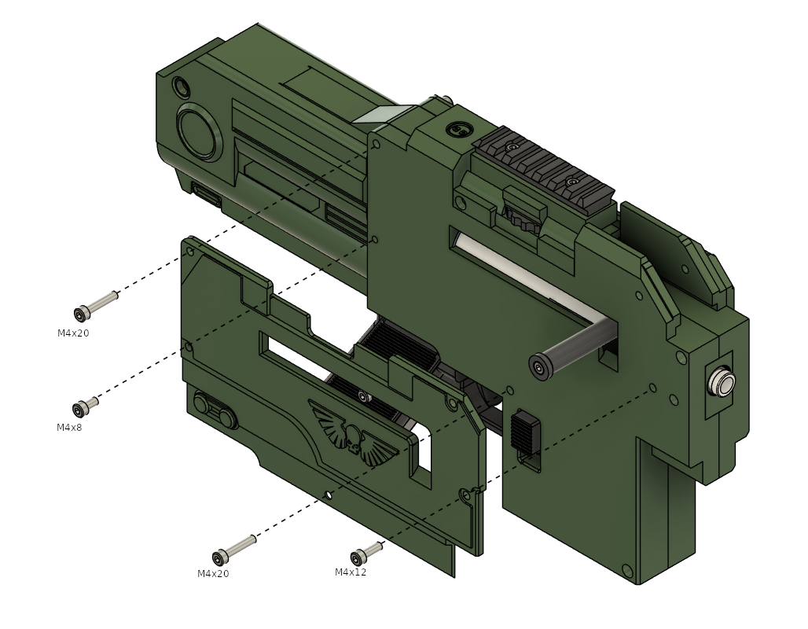
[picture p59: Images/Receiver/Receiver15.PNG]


Clip the Grip Connector to the front underside of the Receiver, and Screw in an M4x20 bolt to complete the receiver.
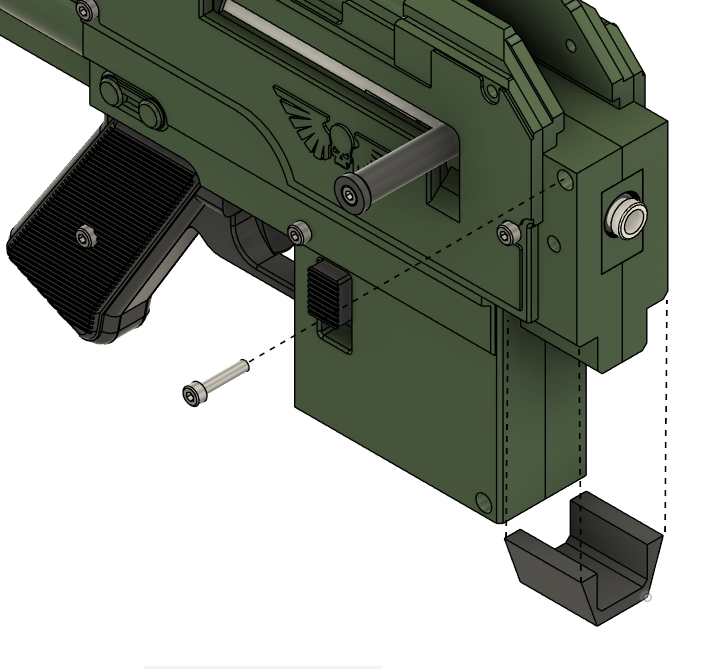
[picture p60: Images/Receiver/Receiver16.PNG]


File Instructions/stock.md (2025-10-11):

# Finishing up.
## Adding the Stock and fitting the barrel


## Recommended Print Orientations
### 3 Walls , 10% infill

### 4 Walls , 15% infill

## Tools
- 3.0mm Hex driver / Key

## Hardware
5x M4x16 Socket Head bolt
2x Heatset Insert

## Assembly

Fit the heat set inserts

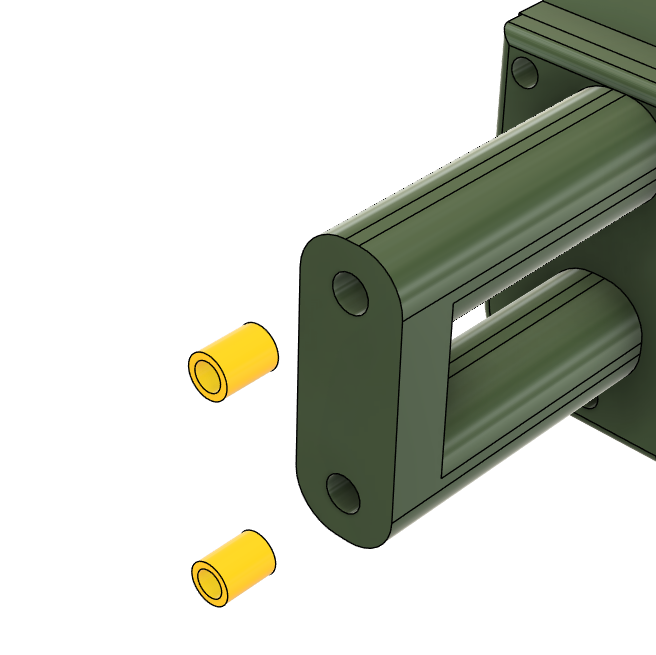
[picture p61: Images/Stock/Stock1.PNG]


Attach the Stock part with three M4x16 bolts.

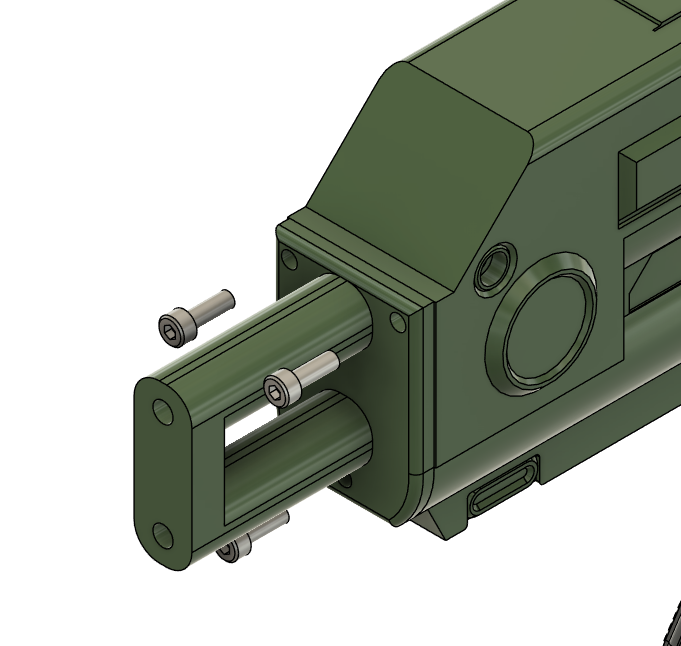
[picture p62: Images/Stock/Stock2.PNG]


Attach the Stock Pad with two M4x16 bolts.

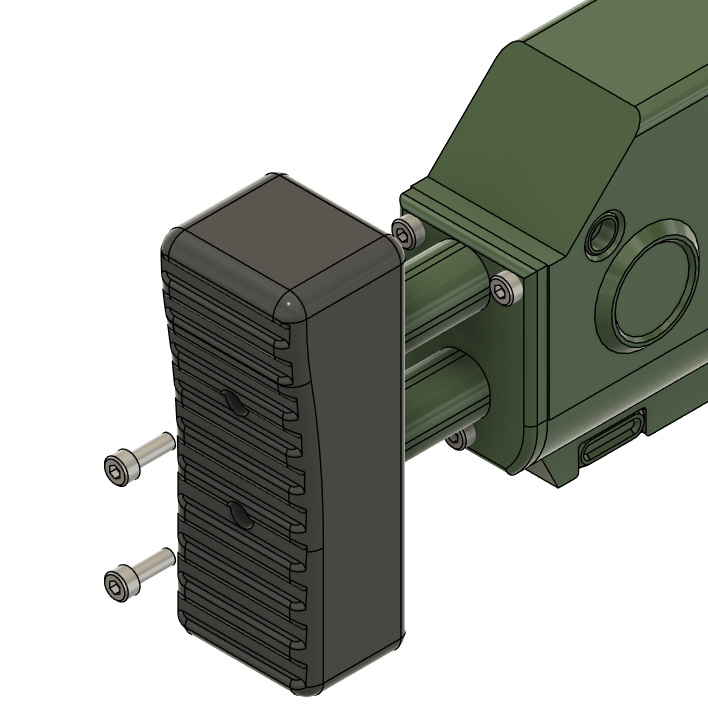
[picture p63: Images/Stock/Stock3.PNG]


Slide the 450mm Barrel into place (and screw in if using the worker barrel) Secure with the Muzzle nut.

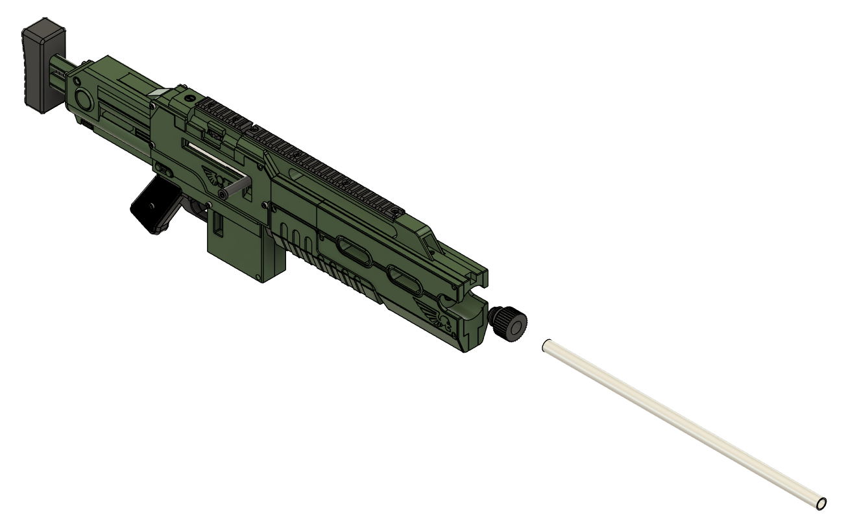
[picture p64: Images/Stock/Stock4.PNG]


And thats it.\
Slap in a mag, and test the whole thing.\
Best of Luck!

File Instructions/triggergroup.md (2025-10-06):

# Assembling the Trigger Group

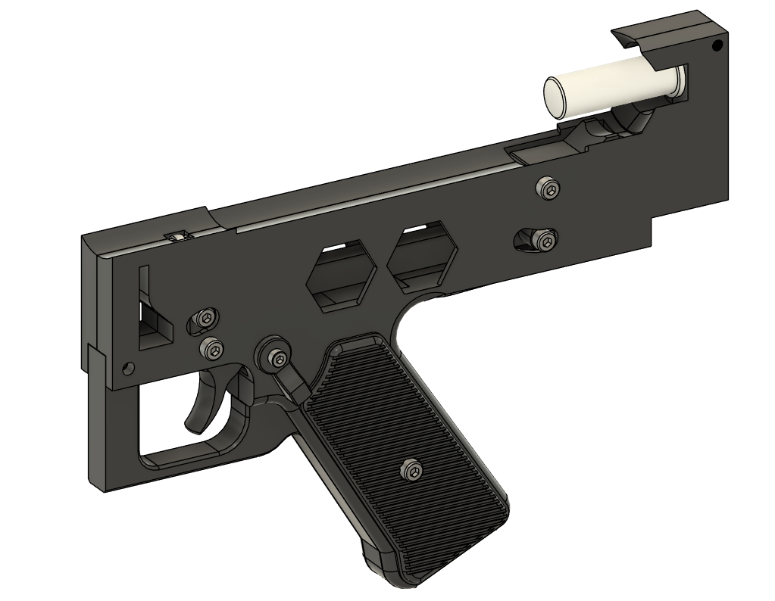
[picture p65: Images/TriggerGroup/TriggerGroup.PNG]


## Recommended Print Orientations
### 3 Walls , 10% infill
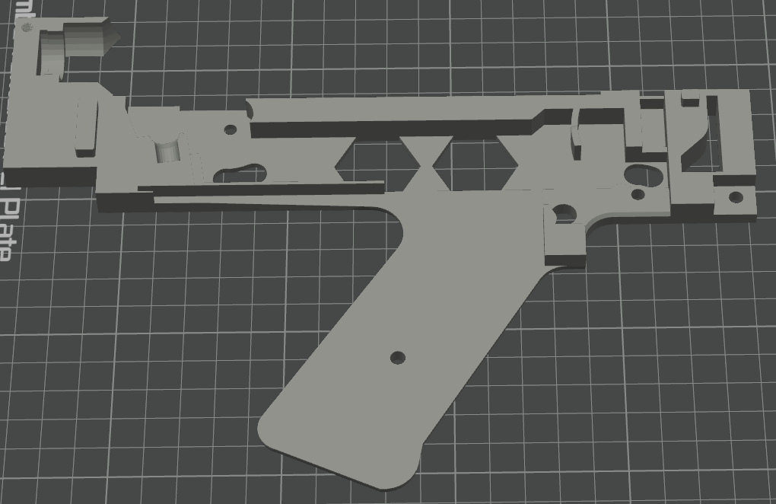
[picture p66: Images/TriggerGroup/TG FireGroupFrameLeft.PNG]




### 4 Walls , 15% infill


## Tools
- 2.5mm Hex driver / Key
- 3.0mm Hex driver / Key
- 3.0mm Drill bit

## Hardware

- 2x Springs
- 1x M4 x 12 Socket Head bolt
- 1x M4 x 16 Socket Head bolt
- 1x M3 x 20 Socket Head bolt
- 2x M4 x 20 Socket Head bolt
- 2x M4 x 10 Socket Head bolt

Build the trigger mechanism, first take the trigger and use a 3mm drill bit and carefully drill the pivot hole, this is printed undersize, and then drilled out to ensure a more exact fit.



Next take the Trigger, Transfer Bar and the Sear, use an M4x12 to connect the trigger to the transfer bar, and an M4x16 the transfer bar to the Sear as shown below.



Next install the Safety Switch into the Fire Group Frame Left. Take the Safety switch and slide it into the frame, in the down / safe position.



Flip the frame over and fit the Safety Cam to the Safety switch exactly as shown below. This is a bit fiddly, but the parts will slide together.
Then screw an M3x20 into the Safety Switch and through into the Safety Cam.
This part should be stiff to move, but still move reasonably freely.



Next take the Fire Group Frame Right, and fit two M4x20 bolts as shown below. Don't worry about taking these out while fitting the Trigger Assembly.



Place a 7x20mm spring inside the box cut out in the Transfer bar. This spring fits onto this little box. This is a little tricky, and you might need to remove the M4 bolts while doing this.



As soon as the Trigger Assembly is on the detent, then make sure the two M4x20 mm bolts are put into place. Then fit the Sear Spring (7x20mm spring) into the Sear at the rear.



Fit the Grip Frame and Spring Holder into the Fire Group Frame Right.



Finally clamp the Fire Group Frame Left and Right together.


 
Fit the Grips (use the locator pins to stop them from rotating) and use an M4x10mm screw to attach them. (do not overtighten these screws)
Optional : Use low Profile screws, or dome screws for improved comfort.
